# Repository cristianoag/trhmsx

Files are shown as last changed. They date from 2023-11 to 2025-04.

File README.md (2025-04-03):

# Introduction

>Unfortunately, there have been reports of unauthorized sales of this computer on platforms like Tindie, AliExpress and other obscure chinese marketplaces. We kindly ask you to support and reward the original creators of this project, who have generously shared their work with the retro community, rather than those engaging in unauthorized distribution. Thank you for respecting the creators' efforts and intentions.

MSX computers hold a significant place in computing history, and their legacy continues to be celebrated through innovative approaches like FPGA synthesis. Field-Programmable Gate Arrays (FPGAs) provide a unique platform for recreating the MSX architecture, offering a flexible and efficient way to re-create the hardware. 

This synthesis enables enthusiasts to experience the charm of MSX systems without relying on original, often scarce, hardware components. FPGA-based MSX simulations can faithfully replicate the distinctive features of these iconic computers, including the Z80 processor, graphics capabilities, and sound architecture. 

This modern approach not only preserves the nostalgia associated with MSX but also opens up possibilities for enhancements and customizations. FPGA synthesis ensures that the MSX spirit endures, catering to both seasoned aficionados and new generations eager to explore the roots of personal computing.

> **WARNING!** If you use this project to implement your own hardware, remember as per the license you must release the modified files under the same license. I've seen multiple projects based on files I publish on Github that were never released to the public, and I think that's a shame (and violation of the license!).

# TRHMSX - A Simple FPGA MSX2+ clone

This FPGA-based MSX2+ hardware represents a straightforward implementation, drawing inspiration from the original 1chipMSX circuit but featuring several enhancements and a new PCB design for improved functionality. Despite its advanced capabilities, the primary focus during development was on maintaining a low-cost solution.

The core of this system is the Cyclone I FPGA, accompanied by a few additional components. The PCB is a 4-layer board measuring 12x15 cm. The FPGA is a 240-pin package, which is challenging to solder manually. Instead, using an SMT oven or a hot air station is advised for optimal results. For those opting for a hot air station, employing a stencil to apply solder paste is highly recommended, significantly streamlining the assembly process.

| Kicad 3D Model | TRHMSX Computer |
|---|---|
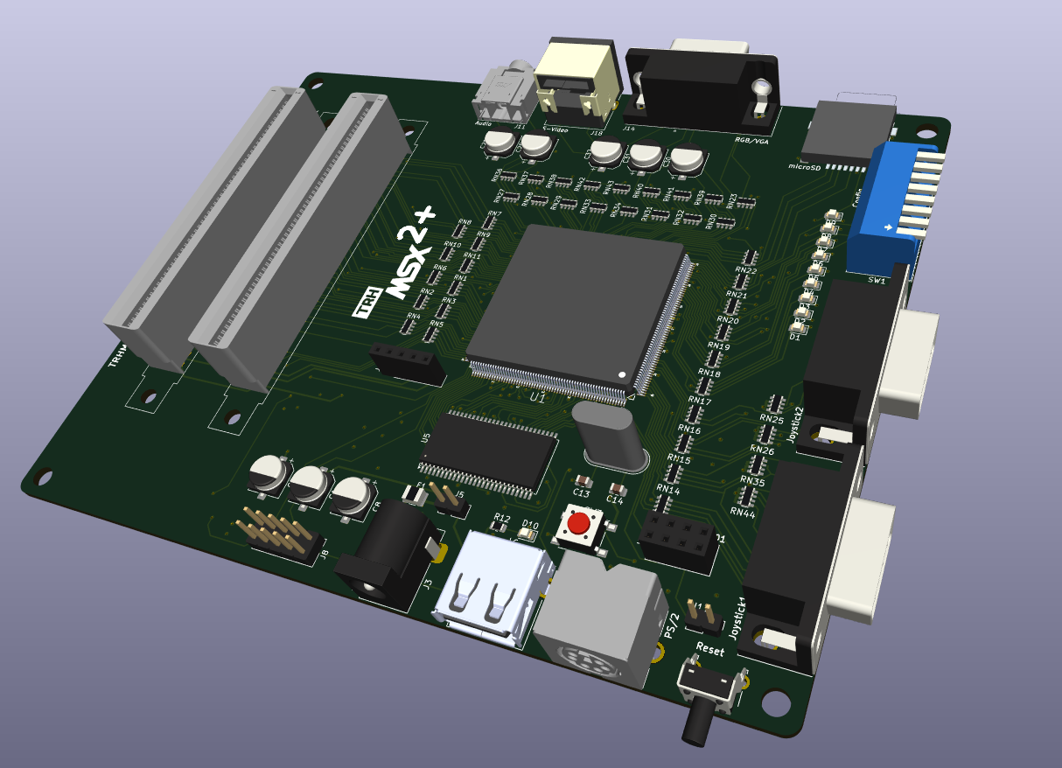
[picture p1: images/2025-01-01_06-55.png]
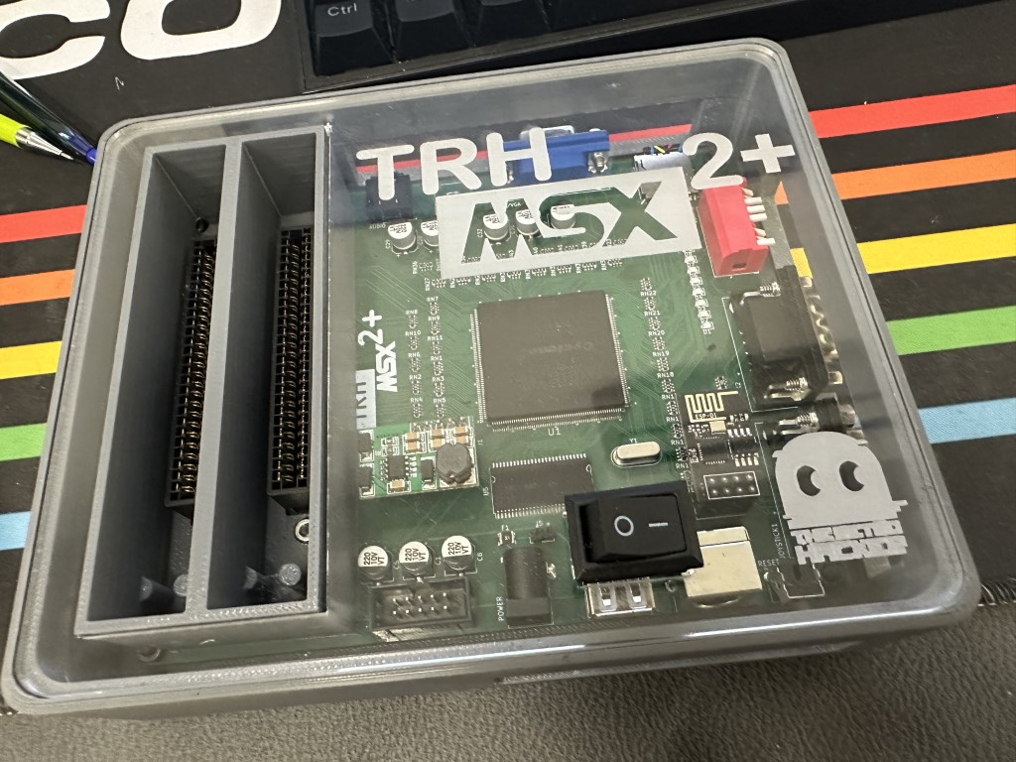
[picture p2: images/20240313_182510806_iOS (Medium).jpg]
|  |  |

Programming the FPGA requires the well-known OCM-PLD ESE MSX2+ core maintained by @gnogni (aka KDL), available for download [here](https://gnogni.altervista.org/) with the main development repository located at https://github.com/gnogni/ocm-pld-dev. This core ensures the proper functioning of the MSX2+ hardware, providing users with a reliable and authentic MSX experience on this FPGA-based system.

## Features

* **MSX2+ Compatibility**: Reproducing the MSX2+ architecture, ensuring compatibility with a wide range of software and games.
* **Expanded Memory Options**: Choose between 2MB or 4MB of mapped RAM, providing users with flexibility for diverse computing needs and applications.
* **9958 Video Display Processor (VDP)**: Incorporating the 9958 VDP for sharp graphics and improved visual performance, delivering an authentic MSX experience.
* **S-Video or VGA/RGB Video Output**: Supporting S-Video output for enhanced video quality or VGA/RGB output for compatibility with modern displays.
* **FM and SCC Sound Capabilities**: Featuring FM synthesis and SCC sound to reproduce the iconic audio characteristics of MSX systems, enhancing the overall gaming and multimedia experience.
* **Programmable Sound Generator (PSG)**: Including the original PSG for standard MSX audio output.
* **Keyboard Compatibility**: Supporting modern USB or PS/2 keyboards, providing users with a choice for their preferred input device.
* **MicroSD Card Support**: Integrating a microSD card slot for convenient storage and easy access to files, games, and software.
* **MSX Cartridge Slots**: Equipped with two MSX cartridge slots, allowing users to explore a vast library of MSX cartridges for an extended range of applications and games.
* **Dual Joystick Ports**: Featuring two joystick ports for multiplayer gaming and compatibility with classic MSX peripherals.
* **Wireless Network Support**: Incorporating wireless network support through the ESP8266, enabling online connectivity and expanding the possibilities for networked applications.
* **12V Cartridge Lines**: Providing dedicated 12V lines for cartridges, ensuring compatibility with a variety of peripherals and accessories.
* **Customizable Case Design**: Offering a 3D-printed base and transparent acrylic top cover, allowing users to customize the appearance of their TRHMSX system.

## Open Source

This project stands as a testament to the spirit of open source collaboration. Over the years, the original 1chipMSX circuit has inspired numerous clones, some even commercially implemented, each potentially harboring unique modifications. Regrettably, many of these adaptations were never shared with the broader community. In response, this project emerges as a fresh implementation of the original circuit, introducing enhancements and a redesigned PCB.

What sets this initiative apart is its commitment to transparency. From the project's inception, the goal was clear: to share all design files openly. This includes not only the schematics and PCB layout but also the Bill of Materials (BOM) and any other essential documentation for recreating the project.

In contrast to its predecessors, this project was conceived with a dedication to community collaboration. If you choose to utilize these resources to construct your own MSX2+ clone or find ways to enhance it, I encourage you to contribute back to the community. 

Share your experiences, document any improvements you make, and actively participate in the collective evolution of this open source initiative.

Let this project serve as a reminder of the **reciprocal nature of open source**. By using and benefiting from open source projects, it becomes a responsibility to give back, ensuring the continued growth and enrichment of the shared knowledge pool within the community.

## Bill of materials

The following table provides a comprehensive list of components required to build the latest version of the TRHMSX project. The BOM details the components, quantities, and references for each part.

I also provide links to the components on AliExpress or other sources, making it easier for you to purchase the necessary parts. 

 > **Note:** I don't have any affiliation with the sellers or guarantee the quality of the products. Please make sure to check the specifications and compatibility of the components before purchasing them.

| **Reference** | **Value** | **Description** | **Qty** | **Link** |
|---|---|---|---|---|
| **PCB** | | | | |
| TRHMSX PCB | N/A | Custom Printed Circuit Board for the TRHMSX 1.51 | 1 | [Gerber Files](hardware/trhmsx/production/TRHMSX_-_The_simple_MSX2_clone_in_FPGA_1.51.zip) |
| **Integrated Circuits (ICs)** | | | | |
| U1 | EP1C12Q240C8N | FPGA Cyclone Family 12060 Cells 275.03MHz 130nm Technology 1.5V 240-Pin PQFP | 1 | [AliExpress](https://s.click.aliexpress.com/e/_DEfxPNr) |
| U2 | AMS1117-1.5V | LOW DROPOUT VOLTAGE REGULATOR (1.5V) | 1 | [AliExpress](https://s.click.aliexpress.com/e/_DEu6go1) |
| U3 | AMS1117-3.3V | LOW DROPOUT VOLTAGE REGULATOR (3.3V) | 1 | [AliExpress](https://s.click.aliexpress.com/e/_DEu6go1) |
| U4 | NC7WZU04P6X | Dual Unbuffered Inverter | 1 | [AliExpress](https://s.click.aliexpress.com/e/_Dk6F9y9) |
| U5 | MT48LC16M16A2TG | 256Mb (4 Megabit x 16 x 4 banks) SYNCHRONOUS DRAM | 1 | [AliExpress](https://s.click.aliexpress.com/e/_DmOI4S5) |
| U6 | M51953BFP | Voltage Detector and System Reset IC | 1 | [AliExpress](https://s.click.aliexpress.com/e/_DnqwGxB) |
| U7 | CH559T | USB Host Micro-controller | 1 | [AliExpress](https://s.click.aliexpress.com/e/_oBU50ZV) |
| U8 | EPCS4 | 4 Mbit Serial Flash Memory (Altera Configuration) | 1 | [AliExpress](https://s.click.aliexpress.com/e/_DD2sMq9) |
| **Resistors** | | | | |
| RN27, RN28, RN29, RN30, RN31, RN32, RN33, RN34 | 200R | 0603X4 200R Resistor Array | 8 | [AliExpress](https://s.click.aliexpress.com/e/_DFFkTit) |
| RN1, RN2, RN3, RN4, RN5, RN6, RN7, RN8, RN9, RN10, RN11, RN13, RN14, RN15, RN16, RN19, RN20, RN21, RN22, RN23, RN36, RN37, RN38, RN39, RN40, RN41, RN42, RN43 | 100R | 0603X4 100R Resistor Array | 28 | [AliExpress](https://s.click.aliexpress.com/e/_DFFkTit) |
| RN12, RN25, RN26, RN35, RN44 | 10KR | 0603X4 10K R Resistor Array | 5 | [AliExpress](https://s.click.aliexpress.com/e/_DFFkTit) |
| RN17, RN18, RN24 | 1KR | 0603X4 1K R Resistor Array | 3 | [AliExpress](https://s.click.aliexpress.com/e/_DFFkTit) |
| R5, R12 | 1KR | 0805 1KR Resistor | 2 | [AliExpress](https://s.click.aliexpress.com/e/_DDTBoqV) |
| R13, R14 | 2.2KR | 0805 2.2KR Resistor | 2 | [AliExpress](https://s.click.aliexpress.com/e/_DDTBoqV) |
| R1, R2 | 10KR | 0805 10KR Resistor | 2 | [AliExpress](https://s.click.aliexpress.com/e/_DDTBoqV) |
| R3, R7 | 10R | 0805 10R Resistor | 2 | [AliExpress](https://s.click.aliexpress.com/e/_DDTBoqV) |
| R8, R9 | 100R | 0805 100R Resistor | 2 | [AliExpress](https://s.click.aliexpress.com/e/_DDTBoqV) |
| R10 | 22R | 0805 22R Resistor | 1 | [AliExpress](https://s.click.aliexpress.com/e/_DDTBoqV) |
| R11 | 1MR | 0805 1MR Resistor | 1 | [AliExpress](https://s.click.aliexpress.com/e/_DDTBoqV) |
| **Capacitors** | | | | |
| C2, C3, C4, C6, C7, C9, C10, C11, C12, C15, C16, C17, C18, C19, C20, C21, C22, C23, C24 | 0.1uF | 0805 100nF Ceramic Capacitor (104) | 19 | [AliExpress](https://s.click.aliexpress.com/e/_Dkt1yD7) |
| C13, C14 | 27pF | 0805 27pF Ceramic Capacitor (270) | 2 | [AliExpress](https://s.click.aliexpress.com/e/_Dkt1yD7) |
| C26, C27 | 4.7uF | 0805 4.7uF Ceramic Capacitor (475) | 2 | [AliExpress](https://s.click.aliexpress.com/e/_Dkt1yD7) |
| C33, C34 | 3.3uF | 0805 3.3uF Ceramic Capacitor (335) | 2 | [AliExpress](https://s.click.aliexpress.com/e/_Dkt1yD7) |
| C25 | 2.2uF | 0805 2.2uF Ceramic Capacitor (225) | 1 | [AliExpress](https://s.click.aliexpress.com/e/_Dkt1yD7) |
| C35 | 10uF | 0805 10uF Ceramic Capacitor (106) | 1 | [AliExpress](https://s.click.aliexpress.com/e/_Dkt1yD7) |
| C1, C5, C8, C28, C29, C30, C31, C32 | 220uF | Electrolytic Capacitor SMD 220uF 10V | 8 | [AliExpress](https://s.click.aliexpress.com/e/_DFJZp0V) |
| **LEDs and Switches** | | | | |
| D1, D2, D3, D4, D5, D6, D7, D8, D9, D10 | Any Color | LED 0805 SMD | 10 | [AliExpress](https://s.click.aliexpress.com/e/_DEuWUBP) |
| SW1 | DIP-SW-8P-RED-90G | Slide Type DIP Sided 90° Switch Module 8Pin Position Way 2.54mm Pitch Red Toggle Switch Blue Snap Switch Dial Switch | 1 | [AliExpress](https://s.click.aliexpress.com/e/_DdFF8Qd) |
| SW2 | BUTDIP90G6x6x12 | Momentary Tactile Tact Push Button Switch Right Angle Horizontal holder With Stent 6*6*12/mm | 1 | [AliExpress](https://s.click.aliexpress.com/e/_DdTON3T) |
| SW3 | BUTSMD180G6x6x4 | 6x6x4.3mm SMD Tactile Push Button Switch 4 Pin | 1 | [AliExpress](https://s.click.aliexpress.com/e/_ophZTzp) |
| **Connectors** | | | | |
| J3 | DC-005 | Female DC Power Jack supply socket 5.5X2.5mm DC-005 5.5-2.5MM Barrel | 1 | [AliExpress](https://s.click.aliexpress.com/e/_DdYmFPj) |
| J11 | PJ-307 | 3.5mm Stereo Jack Socket Audio Jack Connector PCB 3F07 PJ-307 | 1 | [AliExpress](https://s.click.aliexpress.com/e/_DCBm6IH) |
| J4 | MICROSDCARDHOLDER-F | MICROSD Card Holder Card Slot Card Holder Mobile Phone Memory Card Holder With Self-Elastic Long And Short Body | 1 | [AliExpress](https://s.click.aliexpress.com/e/_DeHRUZx) |
| J7 | PS26P-B | Keyboard socket PS2 6P black socket 6-pin Connector | 1 | [AliExpress](https://s.click.aliexpress.com/e/_Dci00lF) |
| J14 | DH15-F-SHORT-B | DH15 DR15 VGA Adapter Socket 3Rows Blue Parallel Port 15 Pin D Sub 15 Way PCB 90 Degree Female Connector | 1 | [AliExpress](https://s.click.aliexpress.com/e/_DEoqLMl) |
| J13, J16 | EDGE-50P | Edge Card Connector PCB Gold Finger 50 Pin | 2 | [AliExpress](https://s.click.aliexpress.com/e/_DkkR9k9) |
| J1 | PH-254-S-F-40 | Round Hole Pin Header 2.54MM Pitch Row Female, Single Row 1x40P | 1 | [AliExpress](https://s.click.aliexpress.com/e/_oFPYktN) |

## Building

To build the project you will need the following tools and resources:

* [Quartus Prime Lite Edition](https://fpgasoftware.intel.com/?edition=lite)
* [Quartus Prime Programmer](https://fpgasoftware.intel.com/18.1/?edition=lite&platform=windows&download_manager=dlm3)
* [USB Blaster drivers](https://fpgasoftware.intel.com/18.1/?edition=lite&platform=windows&download_manager=dlm3)
* [OCM-PLD Pack](https://gnogni.altervista.org/ocm/20221127%20OCM-PLD%20Pack%20v3.9.1%20by%20KdL.7z)

To guide the building process I recommend use the interactive BOM available here [here](https://htmlpreview.github.io/?https://github.com/cristianoag/trhmsx/blob/main/hardware/trhmsx/bom/ibom.html). As you get all the required parts and PCB, use the interactive BOM to check the components and their placement.

## Programming

The programming of the TRHMSX is divided into four main parts: the FPGA, the wireless network module, the USB host micro-controller, and the microSD card.

### FPGA
The firmware for the TRHMSX is based on the first generation esemsx VHDL/Verilog code. You can download the latest packages from KDL page [here](https://gnogni.altervista.org/), or get the latest development versions directly from his GitHub [here](https://github.com/gnogni/ocm-pld-dev).

If you are downloading from the page, you will need the OCM PLD Pack file. Download it and unzip its content in a local file on your PC. If you decide to use GitHub, clone the repository to your PC.

After the unzip, go to the latest version folder and navigate to esemsx3 folder. Check the README file, you will see that you need a pretty old Quartus II version (v11.0 SP1). That is because you are using an obsolete Altera FPGA chip that cannot be programmed by recent versions of the software.

Scrolling down on KDL page you will see a link to download the right version of Quartus. Download and install it.

> **Note:** I had issues with driver certificates for the USB blaster after installing this old version of Quartus. My USB blaster stopped working as the certificates for the driver in v11 are already expired. I reinstalled the latest version of Quartus on the same PC and everything worked fine after that.

Follow the instructions on the README file to compile the appropriate files and program your FPGA. Make sure to follow the instruction to convert the programming file and incorporate the emsx_top_304k.cof file, that way you will have an MSX computer with the EPBIOS. Those steps ensure that you will have the basic BIOS together with the programming file stored on the EPCS4, that will be useful in case you have any issues with the microSD card slot.

Connect your USB Blaster cable and use the Quartus programmer tool to upload the programming file to the EPCS4 flash.

When you turn on your TRHMSX after assembling the PCB, all LEDs should lit. During programming they will flash, turn off and after boot, the TRHMSX will flash the last LED indicating it is loading the synthesis to the FPGA chip, then it will lit only the LEDs that are correspondent to the configuration on the DIP switch bank.

Turn on 2 and 3 to have a 31Khz video and the last one (8) so you enable the SD card. If you need to understand what each dip switch does, check the doc file that is available [here](/docs/TRHMSX_1.5_Quick_Guide_EN.docx).

### USB Host Micro-controller

The latest version of the TRHMSX uses a CH559T micro-controller to handle the USB keyboard interface. That offers the possibility to use almost any USB keyboard with the computer, and not only the ones compatible with the PS/2 protocol.

The circuit from the [HIDMAN micro project](https://github.com/serisman/HIDman-mini/tree/main/KiCad%20PCBs/HIDman-micro) by [@serisman](https://github.com/serisman), based on the [original HIDMAN project](https://github.com/rasteri/HIDman/tree/main) by [Andy (@rasteri)](https://github.com/rasteri) was implemented on the computer. The solution uses the CH559T microcontroller from WCH (Nanjing QinHeng Electronics), a versatile 8051-based chip designed for USB applications.

The HIDMAN micro hardware and firmware offer a reliable way to adapt USB keyboards for PS/2 devices. Open-source hardware truly shines here, allowing to build on the amazing work of the community. Huge thanks to @rasteri and @serisman for their contributions!

To enable USB keyboard support, you’ll need to program the CH559 microcontroller. Here’s how:

1. **Prepare Your Tools**:
    * Download the WCH ISP Tool from [WCH’s website](https://www.wch-ic.com/downloads/WCHISPTool_Setup_exe.html) or from the TRHMSX GitHub repository if needed. I have a copy of the tool available [here](/software/WCHISPTool_Setup.exe).
    * If you are using macOS or Linux, install the [ch55xtool](https://github.com/MarsTechHAN/ch552tool).

2. **Connect Your Hardware**:
    * Power off the TRHMSX.
    * Use a USB A-to-A cable to connect the TRHMSX to your computer.

3. **Program the MCU**:
    * Launch the WCH ISP Tool and select the E8051 USB MCUs family.
    * Ensure the CH559 model is detected. If it isn’t, check the chip installation or bootloader status.
    * Download the pre-configured firmware for TRHMSX from the GitHub repository [here](/hardware/hidman-micro/firmware/dist/hidman.hex).
    * Follow the tool’s prompts to upload the firmware. Please refer to the following images for the tool configuration.

| WCH ISP Configuration| Firmware Download |
|---|---|
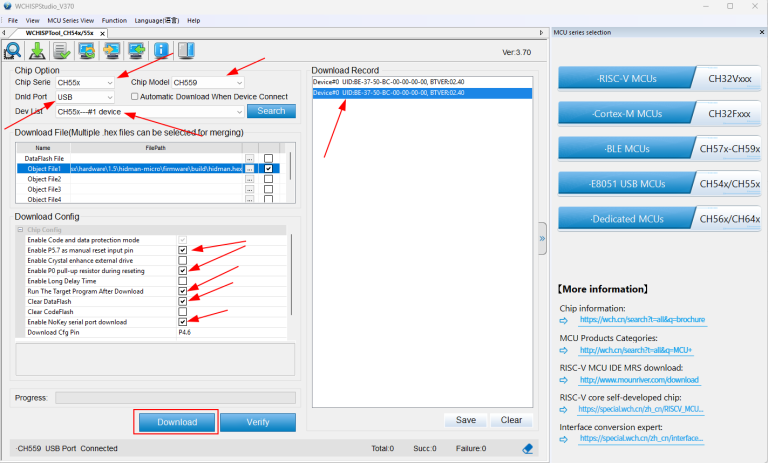
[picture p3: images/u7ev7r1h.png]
WCH ISP Tool
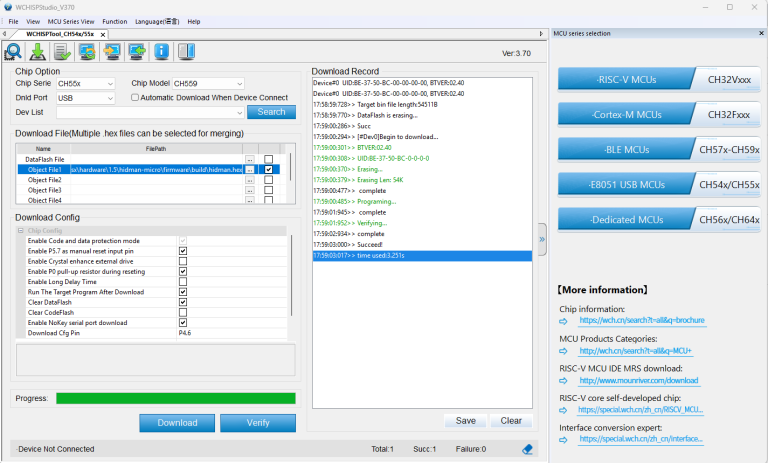
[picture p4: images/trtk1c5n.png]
WCH ISP Tool Configuration
|  |  |

### Wireless Network Module

Wireless network access in the TRHMSX is performed by the use of a 8266 ESP-01 module by Espressif and via the ESP8266 Wi-Fi Support Pack v1.0 shared by KDL as the result of the work of Oduvaldo Pavan Jr. The software created by Oduvaldo is licensed under the GNU Lesser General Public License v2.1 as open source and it is available both from the KDL original web page as well as directly from Oduvaldo's GitHub repository at https://github.com/ducasp/ESP8266-UNAPI-Firmware/ 

Note: Oduvaldo has been working in optimized versions of the ESP8266 module to be used with other FPGA based computers and those may not be compatible with the TRHMSX. Please use the one shared by KDL as it was built to be used with the basic Verilog/VHDL ESEMSX.

#### Programming the ESP8266 module

To program the ESP-01 module you will need a CH340 USB to ESP8266 ESP01 Serial Programmer like the one shown in the below picture. You can purchase one of those directly from AliExpress [here](https://www.aliexpress.com/item/32971145094.html?spm=a2g0o.order_list.order_list_main.30.768e1802iucYdq) (the link is also available on the Bill of Materials table in this document).

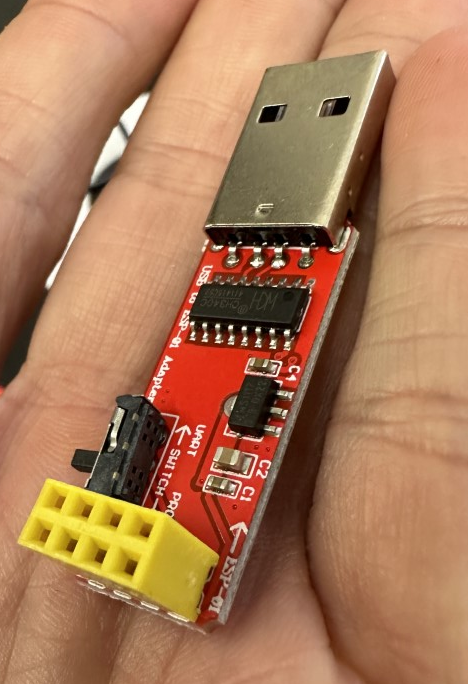
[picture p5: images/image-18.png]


Follow the instructions detailed below to program your ESP8266 module:

1. Download the ESP8266 Wi-Fi Support Pack v1.0 from the KDL page [here](https://gnogni.altervista.org/ocm/20210823%20ESP8266%20Wi-Fi%20Support%20Pack%20v1.0%20by%20KdL.7z). 
2. Make sure the switch on the programmer is configured to PROG.
3. Connect the ESP-01 module to the programmer and insert it to your PC USB port. Open device manager and check the COM port assigned to the programmer. Make sure you have the appropriate CG340 driver installed, if required download and install the driver from wch.cn/downloads/CH341SER_EXE.html

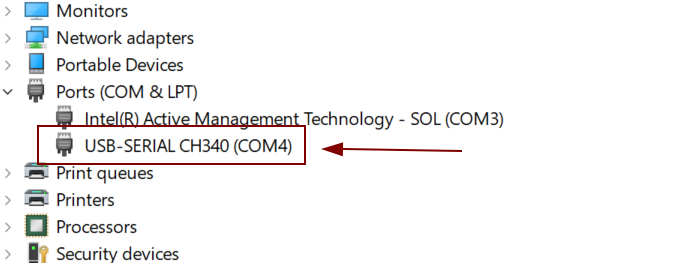
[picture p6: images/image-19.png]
&nbsp;&nbsp;&nbsp;&nbsp;&nbsp;&nbsp;&nbsp;&nbsp;&nbsp;&nbsp;&nbsp;

4. Download Espressif Flash Download Tools from Tools | Espressif Systems
5. Unzip and execute the Flash Download tool from the downloaded zip package. 
6. If asked, select the ESP8266 ChipType and Develop as the WorkMode. Click OK to run the flash download tool.

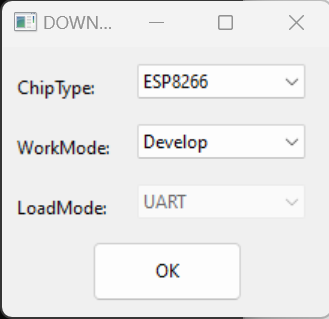
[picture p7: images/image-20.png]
&nbsp;&nbsp;&nbsp;&nbsp;&nbsp;&nbsp;&nbsp;&nbsp;&nbsp;&nbsp;&nbsp;

7. Click the elipsis on the first two lines and make sure to select certs.bin and fw.bin from the package downloaded from the KDL page. Those files are located on the bin folder after unziping the package.  Use 0x0 as the start address for fw.bin and 0xbb000 for certs.bin. Also make sure to select the same COM port as the port identified previously as being used by the CH340 programmer. Reference to the picture below when running the flash download tool to program your ESP8266 module.

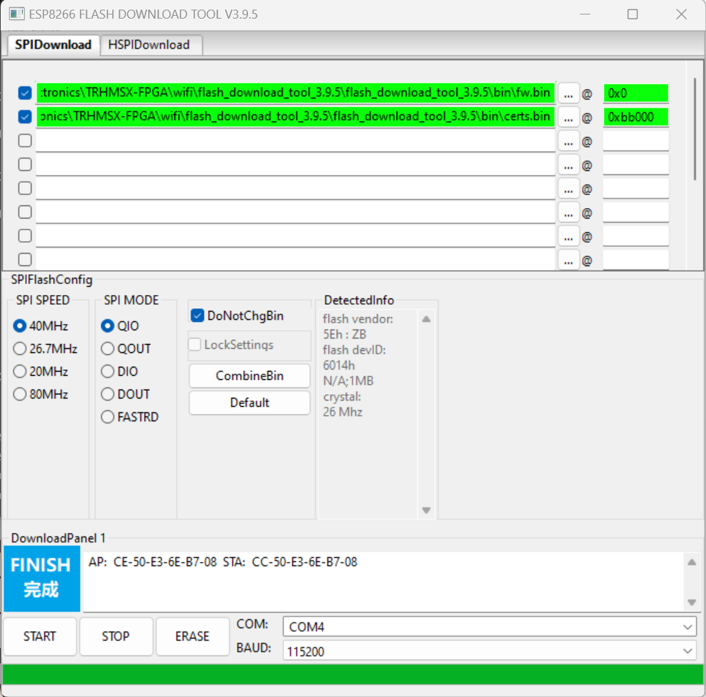
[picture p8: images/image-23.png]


8. The ESP8266 is now ready to be inserted into the TRH MSX pin header dedicated to host the module.

#### Using the TRHMSX with Wireless 

To connect the TRHMSX to your wireless network you need first program the 8266 module according to the instructions previously documented. Then go ahead and plug the module to the appropriate pin headers on the board. Make sure you are connecting it with the right orientation. The location of the header was intentionally chosen to avoid wrong connections as the board cannot be over the SMD electrolytic capacitors located nearby.

Now turn on the TRHMSX and push the F1 key. Keep it pushed until you see the message shown below.

| Entering Network Setup | Config Menu|
|---|---|
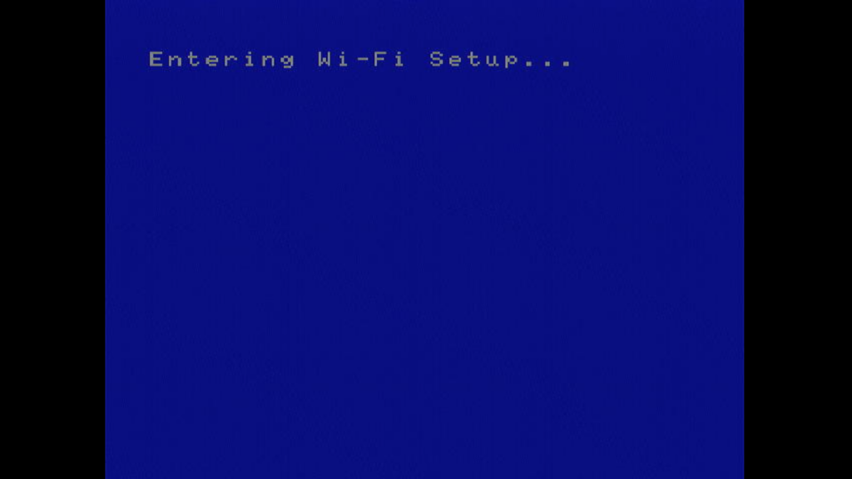
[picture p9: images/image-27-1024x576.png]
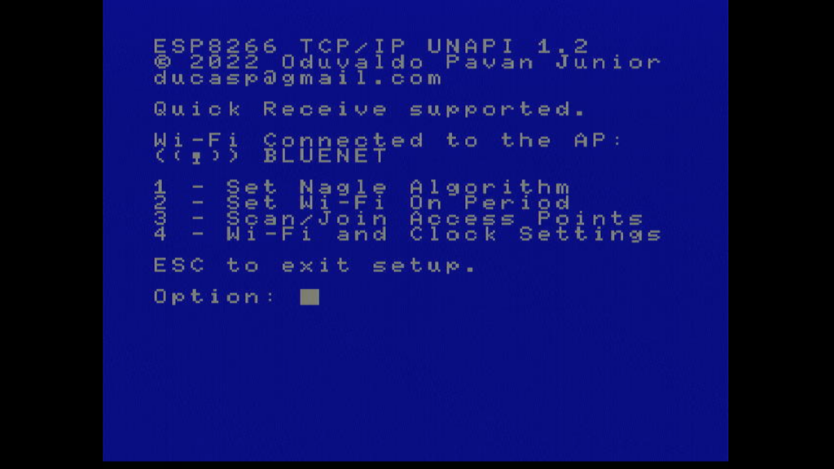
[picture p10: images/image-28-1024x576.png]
||

Note that the second screen already shows it is connected to my local wireless network. You may get a message saying the module is still not connected to any access point. 

Using option 3 you can select a network to connect and provide appropriate credentials. The other options change specific firmware configurations. Please consult the firmware documentation to obtain details on the options and specific configurations.

After connecting the module to your wireless network you can use any UNAPI compatible tool from the computer. Just be aware that the AT firmware variant implemented by Oduvaldo doesn't support ICMP, thus the PING command that we normally use to test the OBSONETs and other traditional network cards will not work from the TRHMSX with the ESP8266 module.

### microSD Card

The microSD card is created by running two tools. The first will build the appropriate files for the card and the second will format, and copy the files to the card.

To configure the files for your microSD card, follow the steps below:

1. Download the latest version of the KDL OCM-SDBIOS pack from the KDL page [here](https://gnogni.altervista.org/).
2. Unzip the downloaded file to a local folder on your PC.
3. Open a command prompt and navigate to the folder where you unzipped the files.
4. Run the make-sdb.cmd tool that is located inside the "make" folder. 
5. Press ENTER on the first screen
6. On the Firmware Menu screen, select option 2 (default) and press ENTER
7. On the Disk-ROM Menu screen, select option 1 (default) and press ENTER
8. On the Main-ROM Menu screen, select option 2 (default) and press ENTER
9. On the Kanji-ROM Menu screen, select the option you want for the splash screen and press ENTER
10. On the Option-ROM Menu screen, select the option 2 to enable the ESP8266 Wifi BIOS for the TRHMSX and press ENTER.
11. On the Extra-ROM Menu screem, select option 3 (default) and press ENTER

Wait until the tool finishes creating the files. After that, you can folow the steps below to build the card using the files you just configured.

1. Insert the microSD card into your PC.
2. Run the SD Card building tool by executing the file named new-sdcard.cmd inside the "make" folder.
3. Select the drive corresponding to your microSD card and press Enter. Optionally provide a name for the partition.
 4. Press any key to create the partition and format the card.

After creating the microSD card, insert it into the TRHMSX and turn on the computer. The TRHMSX will boot from the microSD card and you will see the MSX-DOS prompt.

Optionally, install SofaRun and copy a few ROMs to the card to test the computer.

### +12V/-12V Cartridge Lines

Certain MSX cartridges utilize both the +12V and -12V lines, such as specific variants of OPL4 cartridges and the RBSC Carnivore2. Those lines are crucial for powering the operational amplifiers responsible for audio output.

In the case of the TRHMSX, the +-12V lines are generated through a simple DC Step-up Boost Converter module  connected to the relevant pin headers on the motherboard. 

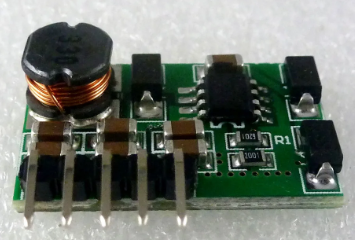
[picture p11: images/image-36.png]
DC Step-up Boost Converter module


The board is powered by the 5V line from the TRHMSX and generates the required +-12V lines. The board is then connected to the TRHMSX motherboard through the relevant pin headers, providing the necessary power for cartridges requiring both +12V and -12V lines.

It can be ordered from AliExpress [here](https://www.aliexpress.com/item/32789671683.html?spm=a2g0o.order_list.order_list_main.16.36c21802vzMe7h).

## Case

The computer case is a combination of a 3D printed bed and a transparent acrylic top cover. There is also the option to print a top cover using transparent or translucid filament or resin. I'm providing Lightburn and STL files for either option on the case folder.

|3D model for the case|First prototype in the case|
|---|---|
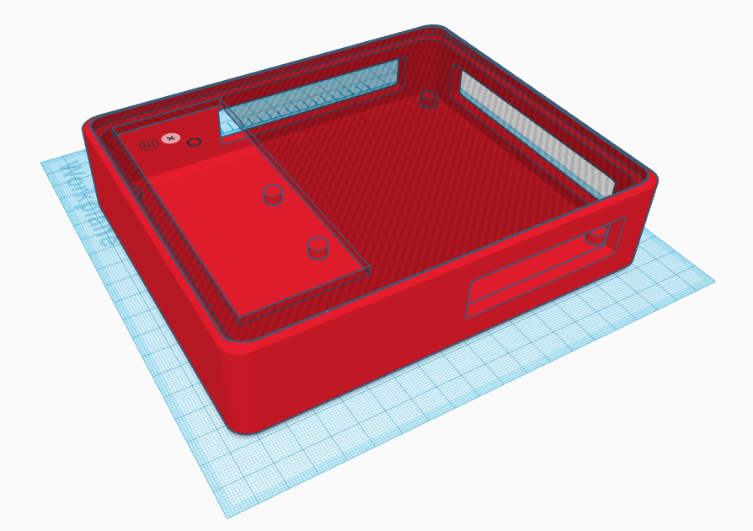
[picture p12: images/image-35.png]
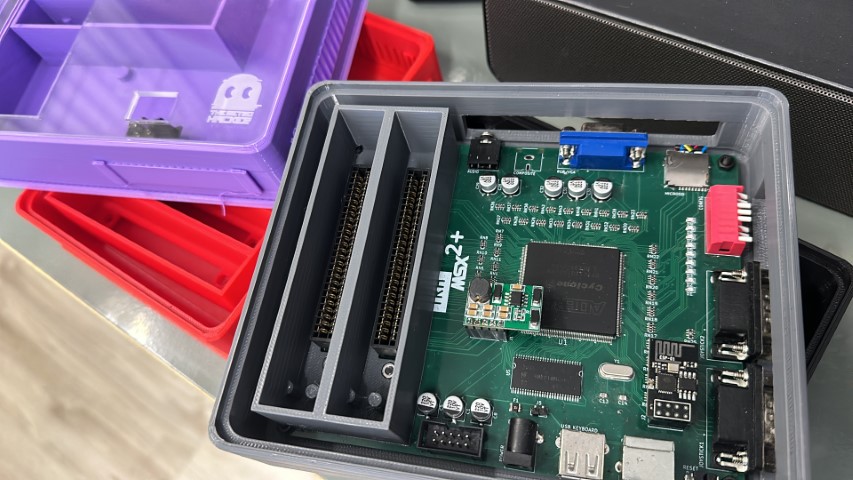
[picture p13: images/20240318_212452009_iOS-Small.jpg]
|||

The STL file to print the case is available [here](case/TRHMSX_case_base_v1.5.stl). You will also need the file to print the cartridge guide [here](case/TRHMSX_cart_guide_v1.4.stl).

Additionally I made available covers for all case and top cover holes so you can protect the computer from dust when not using it. Those files are available on the case folder as well.

The acrylic top is cut from a 3mm transparent acrylic sheet.
The SVG and Light Burn files to cut the acrylic top are available [here](case/). If you decide to print the top cover with the transparent filament or resin, please use the following STL file [TRHMSX_Translucent_Cover.stl](case/TRHMSX_Translucent_Cover.stl)

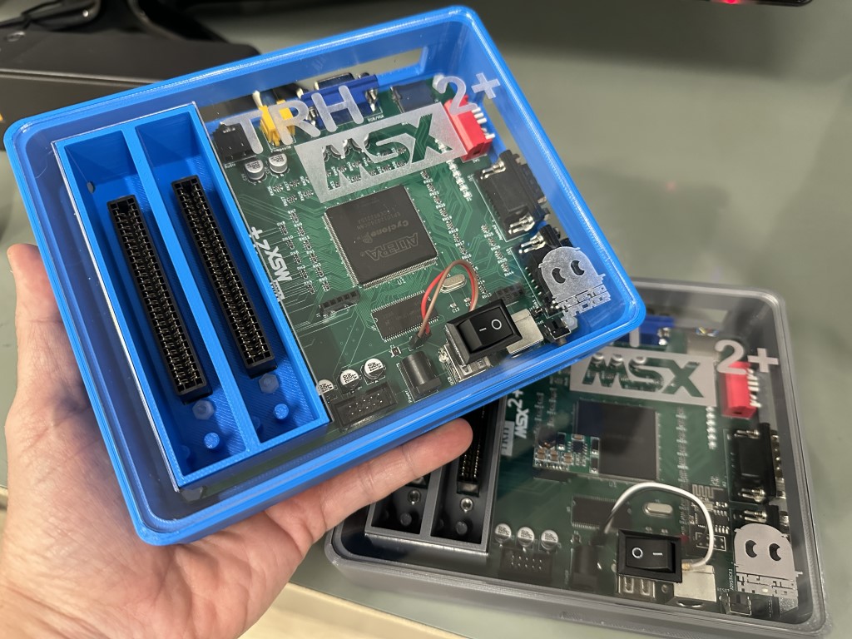
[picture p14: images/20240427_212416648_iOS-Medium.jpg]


## License

Open Hardware

This work is licensed under a [Creative Commons Attribution-NonCommercial-ShareAlike 4.0 International License](http://creativecommons.org/licenses/by-nc-sa/4.0/).

* If you remix, transform, or build upon the material, you must distribute your contributions under the same license as the original.
* You may not use the material for commercial purposes.
* You must give appropriate credit, provide a link to the license, and indicate if changes were made. You may do so in any reasonable manner, but not in any way that suggests the licensor endorses you or your use.

**ATTENTION**

This project was made for the retro community and not for commercial purposes. So only retro hardware forums and individual people can build this project.

THE SALE OF ANY PART OF THIS PROJECT WITHOUT EXPRESS AUTHORIZATION IS PROHIBITED!

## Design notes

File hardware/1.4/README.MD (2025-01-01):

# TRHMSX 1.4

This is the hardware repository for the TRHMSX 1.4. The TRHMSX is a simple FPGA MSX2 clone that uses an Altera Cyclone FPGA to emulate the MSX2 computer. 

The interactive BOM can be found [here](https://htmlpreview.github.io/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).  

Below you can find a list of the components used in the TRHMSX 1.4. The links provided are just suggestions. I don't have any affiliation with the sellers or guarantee the quality of the products. Please make sure to check the specifications and compatibility of the components before purchasing them.

## V1.4 Bill of materials

<table><tbody><tr><td><strong>Reference</strong></td><td><strong>Value</strong></td><td><strong>Description</strong></td><td><strong>Qty</strong></td><td><strong>Link</strong></td></tr><tr><td>TRHMSX PCB</td><td>N/A</td><td>Custom Printer Circuit Board for the TRHMSX 1.0</td><td>1</td><td><a href="https://www.pcbway.com/project/shareproject/TRHMSX_A_Simple_FPGA_MSX2_clone_c575151d.html" data-type="link" data-id="https://www.pcbway.com/project/shareproject/TRHMSX_A_Simple_FPGA_MSX2_clone_c575151d.html">PCBWay</a></td></tr><tr><td>U1</td><td>EP1C12Q240C8N</td><td>FPGA Cyclone Family 12060 Cells 275.03MHz 130nm Technology 1.5V 240-Pin PQFP</td><td>1</td><td><a href="https://s.click.aliexpress.com/e/_DEfxPNr" data-type="link" data-id="https://s.click.aliexpress.com/e/_DEfxPNr">AliExpress</a></td></tr><tr><td>RN27, RN28, RN29, RN30, RN31, RN32, RN33, RN34</td><td>200R</td><td>0603X4 200R Resistor Array</td><td>8</td><td><a href="https://s.click.aliexpress.com/e/_DFFkTit" data-type="link" data-id="https://s.click.aliexpress.com/e/_DFFkTit">AliExpress</a></td></tr><tr><td>RN1, RN2, RN3, RN4, RN5, RN6, RN7, RN8, RN9, RN10, RN11, RN13, RN14, RN15, RN16, RN19, RN20, RN21, RN22, RN23, RN36, RN37, RN38, RN39, RN40, RN41, RN42, RN43</td><td>100R</td><td>0603X4 100R Resistor Array</td><td>28</td><td><a href="https://s.click.aliexpress.com/e/_DFFkTit" data-type="link" data-id="https://s.click.aliexpress.com/e/_DFFkTit">AliExpress</a></td></tr><tr><td>RN12, RN25, RN26, RN35, RN44</td><td>10KR</td><td>0603X4 10K R Resistor Array</td><td>5</td><td><a href="https://s.click.aliexpress.com/e/_DFFkTit" data-type="link" data-id="https://s.click.aliexpress.com/e/_DFFkTit">AliExpress</a></td></tr><tr><td>RN17, RN18, RN24</td><td>1KR</td><td>0603X4 1K R Resistor Array</td><td>3</td><td><a href="https://s.click.aliexpress.com/e/_DFFkTit" data-type="link" data-id="https://s.click.aliexpress.com/e/_DFFkTit">AliExpress</a></td></tr><tr><td>C2, C3, C4, C6, C7, C9, C10, C11, C12, C15, C16, C17, C18, C19, C20, C21, C22, C23, C24</td><td>0.1uF</td><td>0805 100nF Ceramic Capacitor (104)</td><td>19</td><td><a href="https://s.click.aliexpress.com/e/_Dkt1yD7" data-type="link" data-id="https://s.click.aliexpress.com/e/_Dkt1yD7">AliExpress</a></td></tr><tr><td>C13, C14</td><td>27pF</td><td>0805 27pF Ceramic Capacitor (270)</td><td>2</td><td><a href="https://s.click.aliexpress.com/e/_Dkt1yD7" data-type="link" data-id="https://s.click.aliexpress.com/e/_Dkt1yD7">AliExpress</a></td></tr><tr><td>C26, C27</td><td>4.7uF</td><td>0805 4.7uF Ceramic Capacitor (475)</td><td>2</td><td><a href="https://s.click.aliexpress.com/e/_Dkt1yD7" data-type="link" data-id="https://s.click.aliexpress.com/e/_Dkt1yD7">AliExpress</a></td></tr><tr><td>C25</td><td>2.2uF</td><td>0805 2.2uF Ceramic Capacitor (225)</td><td>1</td><td><a href="https://s.click.aliexpress.com/e/_Dkt1yD7" data-type="link" data-id="https://s.click.aliexpress.com/e/_Dkt1yD7">AliExpress</a></td></tr><tr><td>D1, D2, D3, D4, D5, D6, D7, D8, D9</td><td>Any Color</td><td>LED 0805 SMD</td><td>9</td><td><a href="https://s.click.aliexpress.com/e/_DEuWUBP" data-type="link" data-id="https://s.click.aliexpress.com/e/_DEuWUBP">AliExpress</a></td></tr><tr><td>R4, R5, R6</td><td>1KR</td><td>0805 1KR Resistor</td><td>3</td><td><a href="https://s.click.aliexpress.com/e/_DDTBoqV" data-type="link" data-id="https://s.click.aliexpress.com/e/_DDTBoqV">AliExpress</a></td></tr><tr><td>R1, R2</td><td>10KR</td><td>0805 10KR Resistor</td><td>2</td><td><a href="https://s.click.aliexpress.com/e/_DDTBoqV" data-type="link" data-id="https://s.click.aliexpress.com/e/_DDTBoqV">AliExpress</a></td></tr><tr><td>R3, R7</td><td>10R</td><td>0805 10R Resistor</td><td>2</td><td><a href="https://s.click.aliexpress.com/e/_DDTBoqV" data-type="link" data-id="https://s.click.aliexpress.com/e/_DDTBoqV">AliExpress</a></td></tr><tr><td>R8, R9</td><td>100R</td><td>0805 100R Resistor</td><td>2</td><td><a href="https://s.click.aliexpress.com/e/_DDTBoqV" data-type="link" data-id="https://s.click.aliexpress.com/e/_DDTBoqV">AliExpress</a></td></tr><tr><td>R10</td><td>22R</td><td>0805 22R Resistor</td><td>1</td><td><a href="https://s.click.aliexpress.com/e/_DDTBoqV" data-type="link" data-id="https://s.click.aliexpress.com/e/_DDTBoqV">AliExpress</a></td></tr><tr><td>R11</td><td>1MR</td><td>0805 1MR Resistor</td><td>1</td><td><a href="https://s.click.aliexpress.com/e/_DDTBoqV" data-type="link" data-id="https://s.click.aliexpress.com/e/_DDTBoqV">AliExpress</a></td></tr><tr><td>U2</td><td>AMS1117-1.5V</td><td>LOW DROPOUT VOLTAGE REGULATOR (1.5V)</td><td>1</td><td><a href="https://s.click.aliexpress.com/e/_DEu6go1" data-type="link" data-id="https://s.click.aliexpress.com/e/_DEu6go1">AliExpress</a></td></tr><tr><td>U3</td><td>AMS1117-3.3V</td><td>LOW DROPOUT VOLTAGE REGULATOR (3.3V)</td><td>1</td><td><a href="https://s.click.aliexpress.com/e/_DEu6go1" data-type="link" data-id="https://s.click.aliexpress.com/e/_DEu6go1">AliExpress</a></td></tr><tr><td>U5</td><td>MT48LC16M16A2TG</td><td>256Mb (4 Megabit x 16 x 4 banks) SYNCHRONOUS DRAM</td><td>1</td><td><a href="https://s.click.aliexpress.com/e/_DmOI4S5" data-type="link" data-id="https://s.click.aliexpress.com/e/_DmOI4S5">AliExpress</a></td></tr><tr><td>U6</td><td>M51953BFP</td><td>Voltage Detector and System Reset IC</td><td>1</td><td><a href="https://s.click.aliexpress.com/e/_DnqwGxB" data-type="link" data-id="https://s.click.aliexpress.com/e/_DnqwGxB">AliExpress</a></td></tr><tr><td>F1</td><td>FUSEPPTC-1.5A6V</td><td>PPTC Fuse 6V 1.5A 1210</td><td>1</td><td><a href="https://s.click.aliexpress.com/e/_DCOB4CZ" data-type="link" data-id="https://s.click.aliexpress.com/e/_DCOB4CZ">AliExpress</a></td></tr><tr><td>IC1</td><td>EPCS4</td><td>4 Mbit Serial Flash Memory (Altera Configuration)</td><td>1</td><td><a href="https://s.click.aliexpress.com/e/_DD2sMq9" data-type="link" data-id="https://s.click.aliexpress.com/e/_DD2sMq9">AliExpress</a></td></tr><tr><td>U4</td><td>NC7WZU04P6X</td><td>Dual Unbuffered Inverter</td><td>1</td><td><a href="https://s.click.aliexpress.com/e/_Dk6F9y9" data-type="link" data-id="https://s.click.aliexpress.com/e/_Dk6F9y9">AliExpress</a></td></tr><tr><td>C1, C5, C8, C28, C29, C30, C31, C32</td><td>220uF</td><td>Electrolytic Capacitor SMD 220uF 10V</td><td>8</td><td><a href="https://s.click.aliexpress.com/e/_DFJZp0V" data-type="link" data-id="https://s.click.aliexpress.com/e/_DFJZp0V">AliExpress</a></td></tr><tr><td>J3</td><td>DC-005</td><td>Female DC Power Jack supply socket 5.5X2.5mm DC-005 5.5-2.5MM Barrel</td><td>1</td><td><a href="https://s.click.aliexpress.com/e/_DdYmFPj" data-type="link" data-id="https://s.click.aliexpress.com/e/_DdYmFPj">AliExpress</a></td></tr><tr><td>J11</td><td>PJ-307</td><td>3.5mm Stereo Jack Socket Audio Jack Connector PCB 3F07 PJ-307</td><td>1</td><td><a href="https://s.click.aliexpress.com/e/_DCBm6IH" data-type="link" data-id="https://s.click.aliexpress.com/e/_DCBm6IH">AliExpress</a></td></tr><tr><td>J4</td><td>MICROSDCARDHOLDER-F</td><td>MICROSD Card Holder Card Slot Card Holder Mobile Phone Memory Card Holder With Self-Elastic Long And Short Body</td><td>1</td><td><a href="https://s.click.aliexpress.com/e/_DeHRUZx" data-type="link" data-id="https://s.click.aliexpress.com/e/_DeHRUZx">AliExpress</a></td></tr><tr><td>J7</td><td>PS26P-B</td><td>Keyboard socket PS2 6P black socket 6-pin Connector</td><td>1</td><td><a href="https://s.click.aliexpress.com/e/_Dci00lF" data-type="link" data-id="https://s.click.aliexpress.com/e/_Dci00lF">AliExpress</a></td></tr><tr><td>J14</td><td>DH15-F-SHORT-B</td><td>DH15 DR15 VGA Adapter Socket 3Rows Blue Parallel Port 15 Pin D Sub 15 Way PCB 90 Degree Female Connector</td><td>1</td><td><a href="https://s.click.aliexpress.com/e/_DEoqLMl" data-type="link" data-id="https://s.click.aliexpress.com/e/_DEoqLMl">AliExpress</a></td></tr><tr><td>SW1</td><td>DIP-SW-8P-RED-90G</td><td>Slide Type DIP Sided 90o Switch Module 8Pin Position Way 2.54mm Pitch Red Toggle Switch Blue Snap Switch Dial Switch</td><td>1</td><td><a href="https://s.click.aliexpress.com/e/_DdFF8Qd" data-type="link" data-id="https://s.click.aliexpress.com/e/_DdFF8Qd">AliExpress</a></td></tr><tr><td>J12</td><td>RCA-YELLOW-3P</td><td>AV Socket AV-8.4-5 Three Pin Single Hole Socket Yellow Side Bent Foot RCA Lotus Audio Socket Connector</td><td>1</td><td><a href="https://s.click.aliexpress.com/e/_DFjsw5T" data-type="link" data-id="https://s.click.aliexpress.com/e/_DFjsw5T">AliExpress</a></td></tr><tr><td>J6</td><td>USB-A</td><td>USB Type A Standard Port Female Solder Jacks Connector PCB Socket USB-A type</td><td>1</td><td><a href="https://s.click.aliexpress.com/e/_DlKAwlj" data-type="link" data-id="https://s.click.aliexpress.com/e/_DlKAwlj">AliExpress</a></td></tr><tr><td>J8</td><td>BOXED-2x5P-2.54-180</td><td>Straight 10 PIN 2.54MM pitch MALE SOCKET idc box headers PCB CONNECTOR DOUBLE ROW</td><td>1</td><td><a href="https://s.click.aliexpress.com/e/_DdnF7VJ" data-type="link" data-id="https://s.click.aliexpress.com/e/_DdnF7VJ">AliExpress</a></td></tr><tr><td>J15, J10</td><td>DB9-M-LONG-BLACK</td><td>DB9 Male PCB Mount D-Sub 9 pin PCB Connector RS232 Connector 90-degree Bent Needle DR9</td><td>2</td><td><a href="https://s.click.aliexpress.com/e/_DEPBDln" data-type="link" data-id="https://s.click.aliexpress.com/e/_DEPBDln">AliExpress</a></td></tr><tr><td>SW2</td><td>BUTDIP90G6x6x12</td><td>Momentary Tactile Tact Push Button Switch Right Angle Horizontal holder With Stent 6<em>6</em>12/mm</td><td>1</td><td><a href="https://s.click.aliexpress.com/e/_DdTON3T" data-type="link" data-id="https://s.click.aliexpress.com/e/_DdTON3T">AliExpress</a></td></tr><tr><td>Y1</td><td>21.47727 Mhz</td><td>21.47727M 21.47727MHZ 20PF QUARTZ CRYSTAL RESONATOR HC-49S</td><td>1</td><td><a href="https://s.click.aliexpress.com/e/_DmkZXqZ" data-type="link" data-id="https://s.click.aliexpress.com/e/_DmkZXqZ">AliExpress</a></td></tr><tr><td>CART1, CART2</td><td>EDGE-50P</td><td>Edge Card Connector PCB Gold Finger 50 Pin</td><td>2</td><td><a href="https://s.click.aliexpress.com/e/_DkkR9k9" data-type="link" data-id="https://s.click.aliexpress.com/e/_DkkR9k9">AliExpress</a></td></tr><tr><td>N/A</td><td>PH-254-S-F-40-ROUNDED</td><td>Round Hole Pin Header 2.54MM Pitch Row Female/Male, Single Row 1x40P</td><td>1</td><td><a href="https://s.click.aliexpress.com/e/_DlfZNmh" data-type="link" data-id="https://s.click.aliexpress.com/e/_DlfZNmh">AliExpress</a></td></tr><tr><td>N/A</td><td>PH-254-S-M-40-ROUNDED</td><td>2.54mm Pitch Gold Plated Male 40P 1*40 Round Pin Header Strip Hole Single Row Straight Socket Connector</td><td>1</td><td><a href="https://s.click.aliexpress.com/e/_DlfZNmh" data-type="link" data-id="https://s.click.aliexpress.com/e/_DlfZNmh">AliExpress</a></td></tr><tr><td>J2</td><td>ESP-01</td><td>ESP8266 WIFI wireless module wireless transceiver 2.4G ESP-01</td><td>1</td><td><a href="https://s.click.aliexpress.com/e/_Ddjghnr" data-type="link" data-id="https://s.click.aliexpress.com/e/_Ddjghnr">AliExpress</a></td></tr><tr><td>N/A</td><td>ESP-01 Programmer</td><td>CH340 USB to ESP8266 Serial ESP-01 ESP-01S Adapter Wireless Wifi Developent Board ESP01 ESP01S Programmer Adapter GPIO Module</td><td>1</td><td><a href="https://s.click.aliexpress.com/e/_Ddjghnr" data-type="link" data-id="https://s.click.aliexpress.com/e/_Ddjghnr">AliExpress</a></td></tr><tr><td>N/A</td><td>DCDCSTEP12V</td><td>+-12V Positive &amp; Negative Dual Output power supply DC DC Step-up Boost Converter module</td><td>1</td><td><a href="https://www.aliexpress.com/item/32789671683.html?spm=a2g0o.order_detail.order_detail_item.5.5cc6f19ccbtJLv" data-type="link" data-id="https://www.aliexpress.com/item/32789671683.html?spm=a2g0o.order_detail.order_detail_item.5.5cc6f19ccbtJLv">AliExpress</a></td></tr></tbody></table>

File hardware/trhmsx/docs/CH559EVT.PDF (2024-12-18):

## USB 单片机 CH559 的评估板说明

## 1、硬件部分

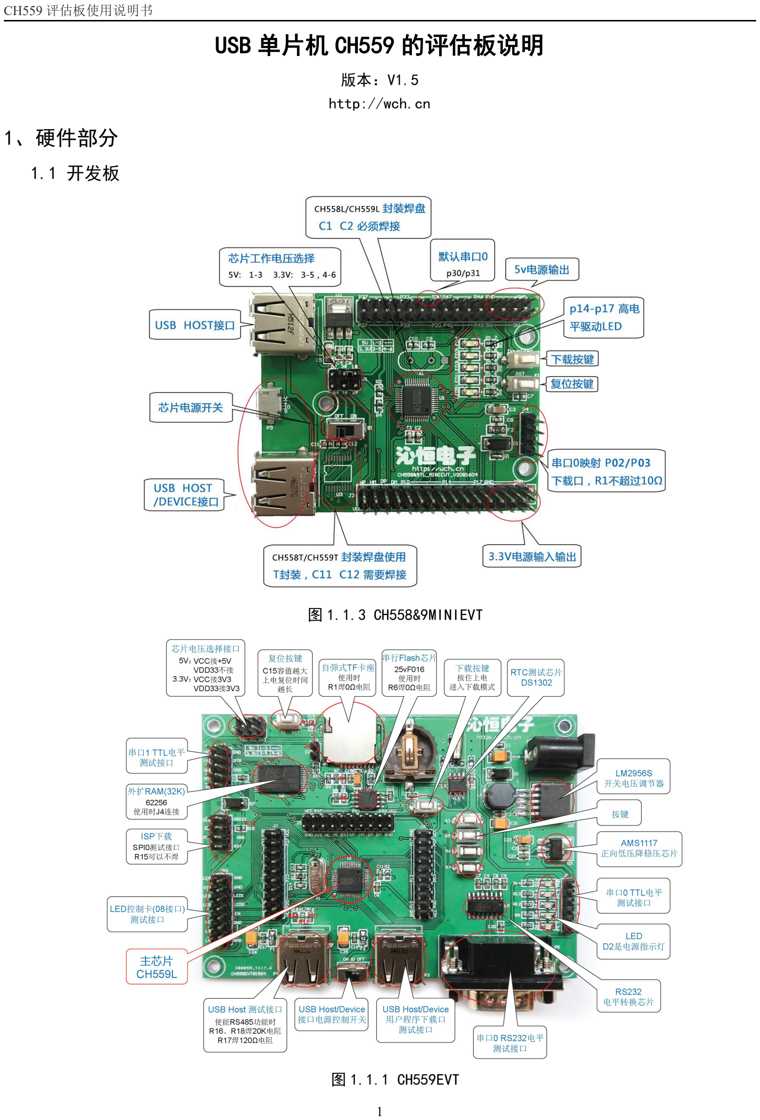
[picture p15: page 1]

CH559 评估板使用说明书

版本：V1.5
http://wch.cn

1.1 开发板

图 1.1.3 CH558&9MINIEVT

图 1.1.1 CH559EVT

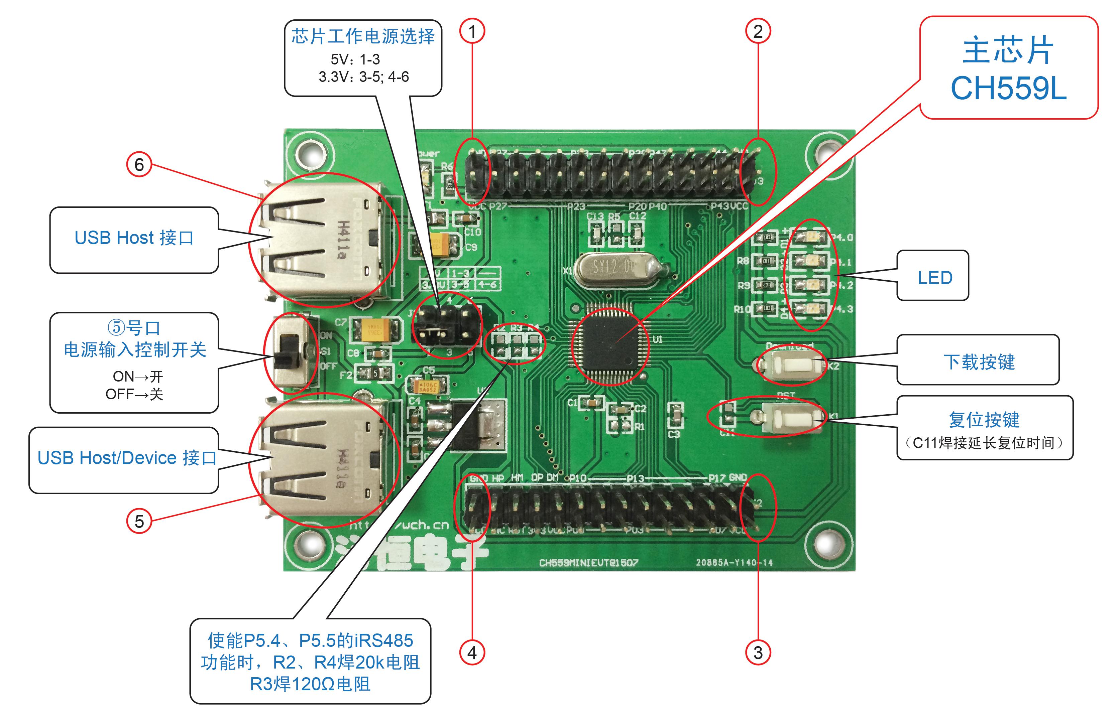
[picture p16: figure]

图 1.1.2 CH559MINIEVT

1.2 开发板主芯片及功能说明
(1)、芯片工作电源选择：芯片电压选择，VCC 和+5V 短接，VDD33 悬空，CH559 的工作电压选为 5V；VCC 和 3V3 短接，VDD33 和 3V3 短接，CH559 工作电压选为 3.3V；
(2)、评估板电源输入：
通过 P1 电源适配器插口输入 8-15V 的电压，如图 1.1.1 的 P1 口；
通过 USB 直接输入 5V 电压，如图 1.1.1 和图 1.1.2 的 USB 口；
通过 VCC 和 GND 插针直接输入 5V 或者 3.3V 电压，图 1.1.1 和图 1.1.2 都可以通过 VCC 和 GND 供电； (3)、复位：C15 默认不焊，若焊接则延长复位时间；
(4)、TF 卡使用 SPI 方式进行操作，使用时 R1 需焊接 0Ω电阻；
(5)、串行 Flash 使用 SPI0 操作，使用时 R6 需焊接 0Ω电阻；
(6)、LED 指示灯连接 P4.0~P4.3,引脚输出低电平点亮相应的 LED； (7)、P5.4/P5.5 支持 iRS485 数据收发，使用时 R16/R18 焊 20K 电阻，R17 接 120Ω电阻； (8)、外扩 RAM 物理连接采用直接地址方式，用法参考例程 XBUS.C，使用时需短接 J4；

## 2、评估板资料包说明

来源：www.wch.cn 搜索 CH559
文件名：CH559EVT.ZIP
资料包：
头文件（C、汇编）
评估板原理图
PCB 图
例程
2.1 CH559.uvproj
功能：CH559 keil4 工程文件,头文件、延时函数、串口 0 初始化等常用函数定义； 2.2 ADC 文件夹
功能：ADC 中断(查询)方式手动和自动采集，ADC 采样时钟设置，电压比较功能函数定义； 2.3 CHIP_ID 文件夹

功能：芯片唯一 ID 号获取函数定义；
2.4 DataFlash 文件夹
功能：DataFlash 擦除读写函数定义；
2.5 Encryption 文件夹
功能：芯片常用加密方法介绍和说明；
2.6 GPIO 文件夹
功能：GPIO 设置和 GPIO 中断使用说明；
2.7 IAP 文件夹
功能：CH559 用户程序跳转至 IAP 升级演示和说明文档，提供上位机软件和源码； 2.8 LED_CTRL 文件夹
功能：CH559LED 控制卡演示，支持 U 盘更新显示内容和掉电数据不丢失； 2.9 PWM 文件夹
功能：PWM1&2 初始化，PWM 占空比设置函数；
2.10 SPI0 文件夹
功能：SPI0 主机从机模式初始化和数据收发演示，主机操作 CH376，从机连接其他 C51 MCU; 2.11 SPI1 文件夹
功能：SPI0 主机模式初始化和数据收发演示，主机操作 CH376;
2.12 Timer0 文件夹
功能：定时器 0 初始化和定时器、计数器使用函数定义； 2.13 Timer1 文件夹
功能：定时器 1 初始化和定时器、计数器使用函数定义；
2.14 Timer2 文件夹
功能：定时器 2 初始化和定时器、计数器使用函数定义，定时器 2 捕捉功能函数定义；
2.15 Timer3 文件夹
功能：定时器 3 初始化和定时器、计数器使用函数定义，定时器 3 捕捉功能函数定义和 PWM3 设置及使用； 2.16 UART0 文件夹
功能：串口 0 初始化和中断收发示例；
2.17 WDOG 文件夹
功能：看门狗初始化和喂狗；
2.18 XBUS 文件夹
功能：并行总线初始化和数据收发函数定义；
2.19 USB_LIB 文件夹
功能：USB 文件系统库；
2.20 USB 文件夹
A．DEVICE 文件夹
模拟 USB 键鼠例程，支持部分类命令；
模拟厂商自定义设备，需要安装 CH372 驱动，可以通过 372test.exe 调试(批量数据收发，中断传输)； B．HOST 文件夹
USB 主机应用例子,初始化和枚举 USB 端口连接的设备,支持一级外部 HUB,可以操作 USB 键鼠和 HUB，打 印机,包含 HID 类命令处理；
C．U_DISK
字节方式读写文件，包括文件创建、删除、修改文件属性,修改文件名； 扇区方式读写文件，包括文件创建、删除、修改文件属性,修改文件名； 创建文件夹和文件创建；
枚举根目录或者指定目下的文件；
2.21 PUB 评估板说明

功能：评估板说明、评估板原理图

## 3、MCU ISP 下载软件说明

3.1 下载前准备

3.1.1 ISP 变更
重要：因为 ISP 工具升级更新，芯片 BOOT 版本 V2.30 以前的版本需要在 V2.40 及以上版本 ISP 工具上选 择支持的 BOOT 版本，以下以 ISPTool（V2.40）为例，默认支持最新 BOOT。
USB 方式下载：无需任何设置，完全兼容。
串口方式下载：如果不知道具体的 BOOT 版本，请咨询技术人员或者销售人员。
BOOT 版本 ＜ V2.30,设置如图 | ，勾选代表设置成功，如果设置成功，ISP 软件名称显
示如： | 。
BOOT 版本 ≥ V2.30，设置如图 | 。

3.1.2 USB 下载
a.根据 1.2 的（1）选择芯片供电电压；
b.按住 | ，将 USB Host/Device 口与 PC 连接；

c.松开 Download 键；
d．使用 ISP 软件下载，具体参考 3.3 的（1）；
3.1.3 串口下载
a. 根据 1.2 的（1）选择芯片供电电压；
b.串口下载使用芯片的 P02（RXD）和 P03（TXD）引脚，将 TXD，RXD 和 GND 与电脑串口连接；
d. （1）按键下载：按住 | ，通过 USB Host/Device 口与 PC 连接供电，松开按键；

（2）无按键下载：ISP 工具选择串口号，点击下载，然后通过 USB Host/Device 口连接 PC 供电；
e. 使用 ISP 软件下载，具体参考 3.3 的（2）；
软件：需安装 WCHISPToolISP 工具，USB 驱动包含在安装包内，设备上电后会自动安装。 网上下载链接：http://wch.cn/download/WCHISPTool_Setup_exe.html
3.2 ISP 软件功能说明
WCHISPToolISP 软件主要功能：
1.通过 USB 接口对 CH559 进行单个下载或一次多个的批量下载或校验； 2.串口对 CH559 进行单个下载或者指定间隔时间的逐个下载校验； 3.EEPROM 的读写；
4.支持 HEX 或 BIN 格式下载；
4.支持界面初始设置的保存和文件导入；

5.支持下载统计显示，操作记录保存至指定文件内；
6.USB 下载方式下，支持设备动态插拔；
7.ISP 软件支持简体中文和英文；

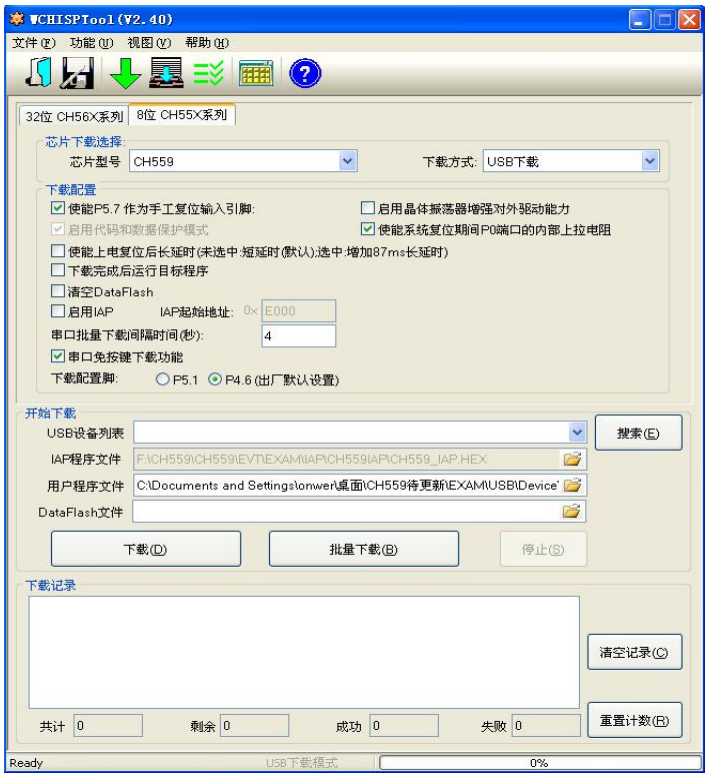
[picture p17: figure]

图 3.1.1 运行 WCHISPTool.exe 主界面

3.3 软件使用说明
(1)、USB 方式下载 MCU 程序：
a.选择芯片系列：点击“8 位 CH55X 系列”标签页面，如 | ；
b.选择芯片型号：在“芯片型号”列表中选择 “CH559”，如 | ；
c.选择下载方式：在“下载方式”列表中选择“USB 下载”，如 | ；

d.下载配置：在“下载配置”栏内，对下载配置进行设置；

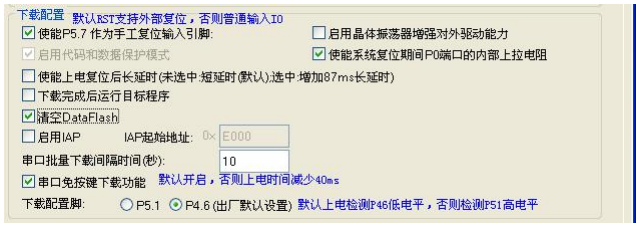
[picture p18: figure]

e.选择下载设备：可以在“USB 设备列表”中选择指定的设备； 如果设备连至 PC，软件检测到，会出现如下图 3.2“USB 列表”显示“型
号 CH559……1 号设备”；
如果没有检测到设备插入，可查看芯片电源连接是否正常，USB 是否连接好等；

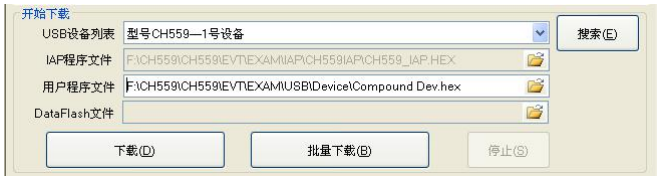
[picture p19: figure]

图 3.3.1
f.选择下载文件：如下载配置中未启用 IAP，只需为 “用户程序文件”选择对应的下载文件； 如启用 IAP ，需为“IAP 程序文件”和“用户程序文件”选择对应的下载 文件；
g.单个下载：点击“下载(D)”按钮进行单个设备的下载
批量下载：如下载类型为“USB 下载”，点击“批量下载 (B)”按钮，会同时对多个设备 进行下载；
如下载类型为“串口下载”，点击“批量下载 (B)”按钮，根据“串口批量下 载间隔时间”,如图 3.5；
来检测设备的接入后自动进行下载，直至点击“停止(S)”按钮结束批量下载； h.如果下载配置中选中“下载完成后自动运行程序”，则 MCU 会在下载完后自退出下载模式，自动加载 运行用户程序；如果未选中，则需要手工给硬件复位或重上电，加载运行用户程序。 i.下载结束，软件会在“下载记录”栏显示当前下载状态，下载成功如图 3.3.2；

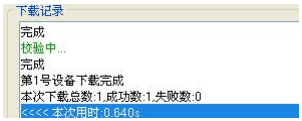
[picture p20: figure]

图 3.3.2
(2)、串口下载 MCU 程序：
a.选择芯片系列：点击“8 位 CH55X 系列”标签页面； b.选择芯片型号：在“芯片型号”列表中选择 “CH559”； c.选择下载方式：在“下载方式”列表中选择“串口下载”； d.下载配置：在“下载配置”栏内，对下载配置进行设置； e.选择下载设备：可以在“串口设备列表”中选择与评估板相连的串口号：

图 3.3.3
f.选择下载文件：如未启用 IAP，只需为 “用户程序文件”选择对应的下载文件； 如启用 IAP ，需为“IAP 程序文件”和“用户程序文件”选择对应的下载 文件；
g.单个下载：点击“下载(D)”按钮进行单个设备的下载 批量下载：如下载类型为“串口下载”，点击“批量下载 (B)”按钮，根据“串口批量下 载间隔时间来检测设备的接入后自动进行下载，直至点击“停止(S)”按钮结束批量下载； 检测设备插入的间隔时间，

图 3.3.4
h.如果选中“下载完成后自动运行程序”，则 MCU 会自退出下载模式，自动加载运行用户程序；如果未 选中，则需要手工给硬件重上电后，加载运行用户程序。
i.下载结束，软件会在“下载记录”栏显示当前下载状态，下载成功如图 3.3.5；

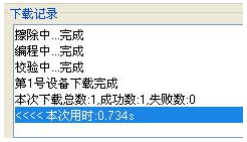
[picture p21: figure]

图 3.3.5
(3)、MCU 程序校验：
a.执行 ISP 下载步骤 a、b、c、d、e、f;
b.点击标题栏上的 | 图标或菜单栏的“功能”->“校验”按钮进行 MCU 烧录代码和指定的“用户

程序文件”进行对比，“下载配置”的设置与 MCU 烧录时的配置进行对比。
(4)、MCU 内置 EEPROM 读写
a.执行 ISP 下载步骤 a、b
b.点击 | 图标，在弹出的“DataFlash”窗口内进行 EEPROM 的读写和保存操作；

（5）、ISP 工具选择语言界面

(6)、 ISP 工具配置保存

a.ISP 工具支持保存配置功能，该功能支持将当前 ISP 工具的配置保存，生成 | 配置文件，
目录可以自己制定，默认和 ISP 工具在同一目录下。

b.ISP 工具支持将 a 保存的配置导入，默认搜索 ISP 工具安装目录下的后缀.INI 文件，将 ISP 工具设置成 保存的配置。

c.恢复默认配置。

## 4、创建工程-编译工具 KEIL

4.1 运行编译器

点击“Project”,如下图选择“New μVision Project…”,弹出一对话框，如下图 3.1.1 所示，选择创建 工程的目录，输入文件名，点击“保存”。

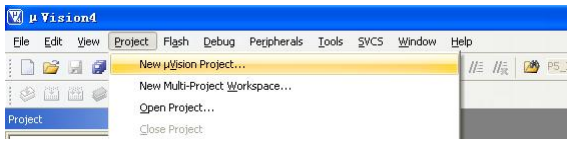
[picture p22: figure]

图 4.1.1
4.2 MCU 器件库添加与选择
(1)、打开 WCHISPTool（V2.6 及以上版本），选择功能→添加 WCH MCU 到 KEIL 器件库。如图 4.2.1 所示。 此时软件会提示“WCH MCU 库添加成功”即可（如图 4.2.2）。

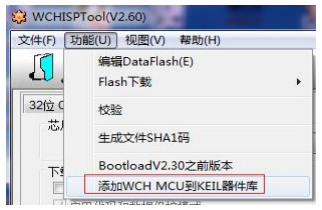
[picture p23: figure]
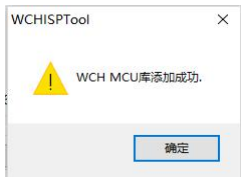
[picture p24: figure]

图 4.2.1 | 图 4.2.2
(2)、打开 Keil C51 工具，创建工程项目。按图 4.2.3 所示 1~3 选择 CH554 芯片。确定后，弹出图 4.2.4 所示窗口，点击“否”即可。

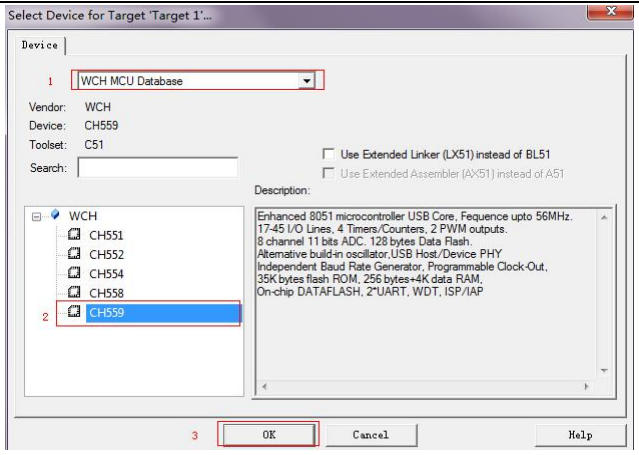
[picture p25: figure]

图 4.2.3

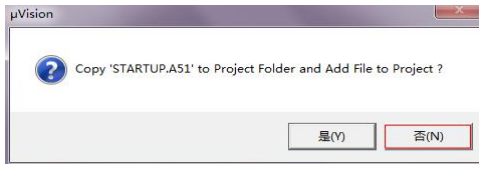
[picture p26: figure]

图 4.2.4
4.3 文件添加
(1)、工程文件打开或者创建完成后，需要添加或者新建程序文件(.C 或者.ASM)，如下图，右击“Source Group1”选择“Add Files To Group ‘Source Group1’”

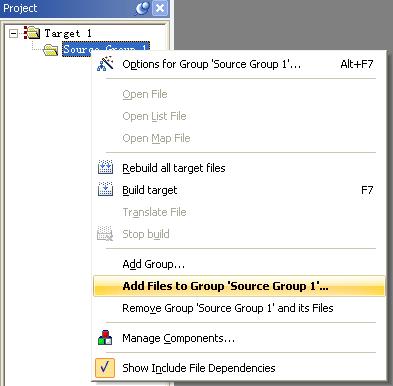
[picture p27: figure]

图 4.3.1
(2)、找到.C 或者.ASM 文件所在目录，选择文件，点击“Add”添加进工程。

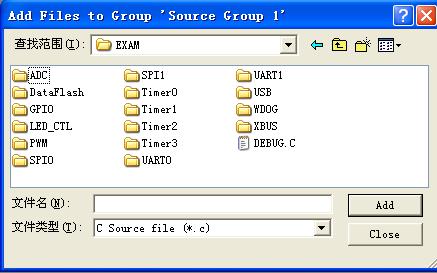
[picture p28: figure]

图 4.3.2

3.4 编译

点击 | ，出现图 4.4.1，勾选“Create HEX File”，点击“OK”，按 F7 或者 | 编译，生成“.HEX”
的文件。

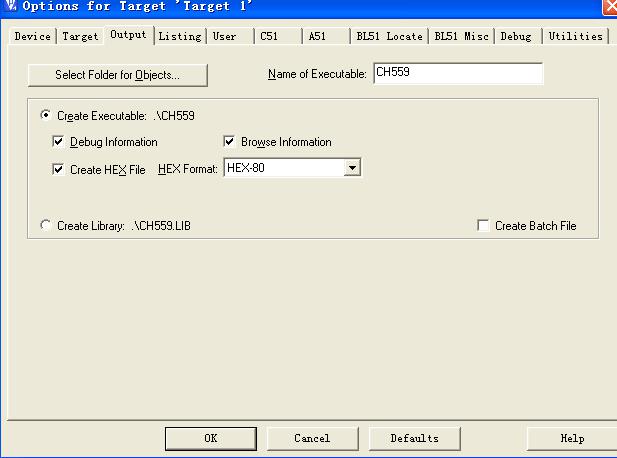
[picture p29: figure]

图 4.4.1

## 5、修改记录

版本 | 日期 | 说明
V1.0 | 2015.5.27 | 初版发行
V1.1 | 2015.10.16 | 1.增加 CH559MINIEVT 的评估板说明； 2.下载说明部分重新调整； 3.增加 IAP 程序下载说明；
V1.2 | 2016.12.08 | 1.增加 CH559MINIEVTV13 的评估板说明； 2.ISP 增加串口批量烧录功能；
V1.3 | 2017.03.06 | 1.ISP 工具升级，下载说明步骤调整；

2.增加 EVT 资料说明；
V1.4 | 2018.02.28 | 1.ISP 工具升级，修改使用说明；
V1.5 | 2018.07.30 | 1.添加 CH55x 设备器件库以及器件选择

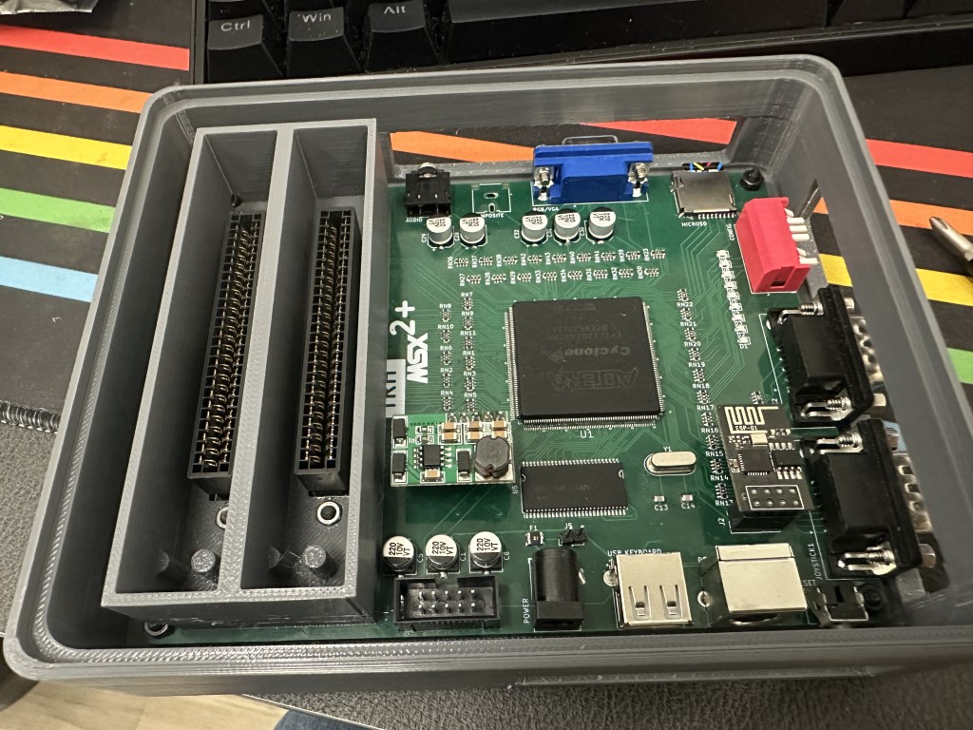
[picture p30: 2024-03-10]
images/20240229_213756238_iOS (Medium).jpg

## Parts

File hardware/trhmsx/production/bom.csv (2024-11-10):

Designator | Footprint | Quantity | Value | LCSC Part #
C1, C28, C29, C30, C31, C32, C5, C8 | CP_Elec_6.3x3 | 8 | 220uF
C10, C11, C12, C15, C16, C17, C18, C19, C2, C20, C21, C22, C23, C24, C3, C4, C6, C7, C9 | 0805 | 19 | 0.1uF
C13, C14 | 0805 | 2 | 27pF
C25 | 0805 | 1 | 2.2uF
C26, C27 | 0805 | 2 | 4.7uF
C33, C34 | 0805 | 2 | 3.3uF
C35 | 0805 | 1 | 10uF
D1, D10, D2, D3, D4, D5, D6, D7, D8, D9 | 0805 | 10 | LED3
F1 | 1210 | 1 | Fuse
J1 | PinSocket_1x05_P2.54mm_Vertical | 1 | MODULE-12V
J10 | DSUB-9_Male_Horizontal_P2.77x2.84mm_EdgePinOffset4.94mm_Housed_MountingHolesOffset7.48mm | 1 | JOY2
J11 | PJ-307 | 1 | AudioJack2_Ground
J13 | TE_5530841-5 | 1 | CART2
J14 | DSUB-15-HD_Female_Horizontal_P2.29x1.98mm_EdgePinOffset3.03mm_Housed_MountingHolesOffset4.94mm | 1 | DH15
J15 | DSUB-9_Male_Horizontal_P2.77x2.84mm_EdgePinOffset4.94mm_Housed_MountingHolesOffset7.48mm | 1 | JOY1
J16 | TE_5530841-5 | 1 | CART1
J17, J5 | PinHeader_1x02_P2.54mm_Vertical | 2 | Conn_01x02
J18 | CUI_MD-40SM | 1 | S-Video
J2 | PinSocket_2x04_P2.54mm_Vertical | 1 | ESP-01
J3 | BarrelJack_Horizontal | 1 | Barrel_Jack
J4 | Conn_uSDcard | 1 | MICRO-SD
J6 | TE_6364372-2 | 1 | KEYBOARD-USB
J7 | TE_5749180-1 | 1 | KEYBOARD-PS2
J8 | PinHeader_2x05_P2.54mm_Vertical | 1 | Conn_02x05_Odd_Even
R1, R2 | 0805 | 2 | 10K
R10 | 0805 | 1 | 22
R11 | 0805 | 1 | 1M
R12, R5 | 0805 | 2 | 1K
R13, R14 | 0805 | 2 | 2.2K
R3, R7 | 0805 | 2 | 10
R8, R9 | 0805 | 2 | 100
RN1, RN10, RN11, RN13, RN14, RN15, RN16, RN19, RN2, RN20, RN21, RN22, RN23, RN3, RN36, RN37, RN38, RN39, RN4, RN40, RN41, RN42, RN43, RN5, RN6, RN7, RN8, RN9 | R_Array_Convex_4x0603 | 28 | 100
RN12, RN25, RN26, RN35, RN44 | R_Array_Convex_4x0603 | 5 | 10K
RN17, RN18, RN24 | R_Array_Convex_4x0603 | 3 | 1K
RN27, RN28, RN29, RN30, RN31, RN32, RN33, RN34 | R_Array_Convex_4x0603 | 8 | 200
SW1 | SW_DIP_SPSTx08_Piano_10.8x21.88mm_W7.62mm_P2.54mm | 1 | SW_DIP_x08
SW2 | SW_Tactile_SPST_Angled_PTS645Vx83-2LFS | 1 | SW_Push
SW3 | SW_Push_1P1T_NO_6x6mm_H9.5mm | 1 | SW_Push
U1 | QFP50P3460X3460X410-240N | 1 | EP1C12Q240C8N | EP1C12Q240C8N
U2 | SOT-223-3_TabPin2 | 1 | AMS1117-1.5
U3 | SOT-223-3_TabPin2 | 1 | AMS1117-3.3
U4 | SOT65P210X110-6N | 1 | NC7WZU04P6X
U5 | TSOP-II-54_22.2x10.16mm_P0.8mm | 1 | MT48LC16M16A2TG
U6 | SO08 | 1 | M51953BFP
U7 | SSOP-20_5.3x7.2mm_P0.65mm | 1 | CH559T
U8 | SO08 | 1 | EPCS4
Y1 | Crystal_HC49-U_Vertical | 1 | 21.47727 MHz

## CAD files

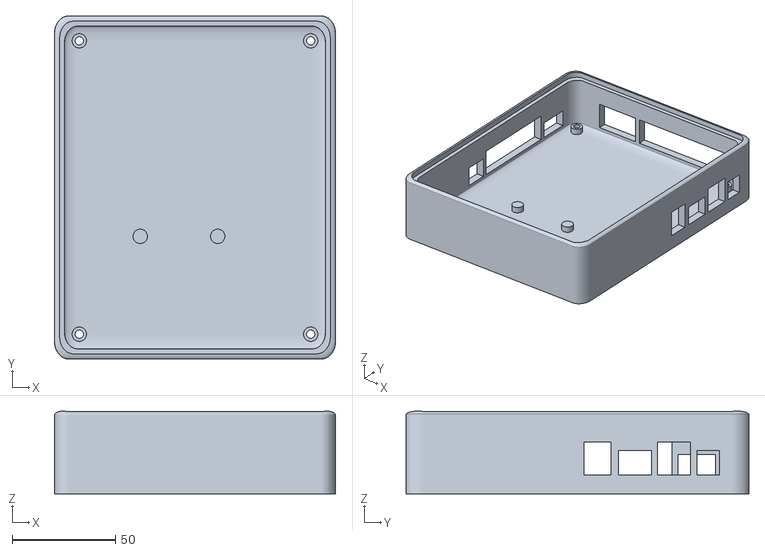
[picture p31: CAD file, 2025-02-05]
case/TRHMSX_case_base_v2.0.stl
136.0 x 166.0 x 40.0

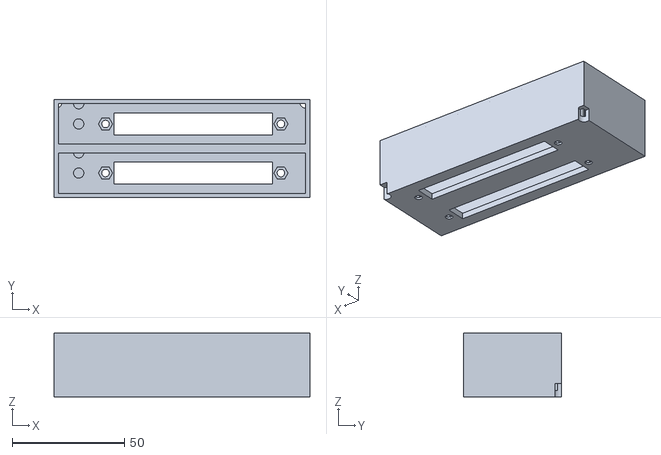
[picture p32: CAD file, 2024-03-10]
case/TRHMSX_cart_guide_v1.4.stl
114.0 x 43.9 x 28.5

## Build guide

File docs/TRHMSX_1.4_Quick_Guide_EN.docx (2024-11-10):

# The Retro Hacker - TRHMSX – Quick User Guide – 1.0

THANK YOU FOR YOUR PURCHASE!

Just like you, I love MSX, and this computer was carefully built in my laboratory for you. I don't make a living by selling these things on the Internet, it's my hobby, and all profits go towards building new projects and keeping the MSX alive.

Please, if you have any issues with the computer, let me know immediately. I want you to have the same experience I desire as a buyer.

This FPGA-based MSX2+ hardware represents a straightforward implementation, drawing inspiration from the original 1chipMSX circuit but featuring several enhancements and a new PCB design for improved functionality.

TRHMSX features:

- MSX2+ Compatibility: Reproducing the MSX2+ architecture, ensuring compatibility with a wide range of software and games.
- Expanded Memory Options: Choose between 2MB or 4MB of mapped RAM, providing flexibility for diverse computing needs and applications.
- 9958 Video Display Processor (VDP): Incorporating the 9958 VDP for sharp graphics and improved visual performance, delivering an authentic MSX experience.
- FM and SCC Sound Capabilities: Featuring FM synthesis and SCC sound to reproduce the iconic audio characteristics of MSX systems, enhancing the overall gaming and multimedia experience.
- Programmable Sound Generator (PSG): Including the original PSG for standard MSX audio output.
- Keyboard Compatibility: Supporting PS/2 keyboards with the option for USB keyboards, providing users with a choice for their preferred input device.
- MicroSD Card Support: Integrating a microSD card slot for convenient storage and easy access to files, games, and software.
- MSX Cartridge Slots: Equipped with two MSX cartridge slots, allowing users to explore a vast library of MSX cartridges for an extended range of applications and games.
- Dual Joystick Ports: Featuring two joystick ports for multiplayer gaming and compatibility with classic MSX peripherals.
- Wireless Network Support: Incorporating wireless network support through the ESP8266, enabling online connectivity and expanding the possibilities for networked applications.
- 12V Cartridge Lines: Providing dedicated 12V lines for cartridges, ensuring compatibility with a variety of peripherals and accessories.
- MIDI Output: Generates MIDI output over the Joystick Port 2 (needs a custom cable and a MIDI player).

This guide was created to help you get started with setting up and using your new computer. It comes already set up with 2MB of RAM, and with a pre-built microSD card that has MSXDOS 2 and the newest version of SofaRUN ready to go. I've even tossed in some ROM files from my own collection so you can dive right into enjoying your MSX experience from the get-go.

## Power Source

Your computer is equipped with a 5V 2A power source (center positive), which is connected via a 2.1mm jack. It's essential to be cautious if you consider using a different power source, as connecting power sources with higher voltages can potentially harm the computer, leading to the need for repairs. Always stick to using the provided power source or an equivalent one (5V 2A) to ensure the safety and proper functioning of your computer.

## Configuration (Dipswitch)

On the side of your computer, you'll notice an eight-position dipswitch (in red). This handy feature allows you to customize various settings for your TRHMSX. Refer to the table below for a detailed description of each available configuration.

DIP-SW | FUNCTION | OPTION | DESCRIPTION
1 | CPU Clock | OFF | Standard mode 3.58MHz
| | ON | Custom Speed mode 4.10MHz to 8.06MHz (10.74MHz on system bus) • Press [F12] key to change clock type (3.58MHz >> 5.37MHz >> Custom Speed) • The external clock is set on [Sync to CPU] by default • [Turbo Pana] is 5.37MHz like the original specification • A special hybrid clock [Turbo MegaSD] is enabled by default
2/3 | Video Output | OFF/OFF | Composite • 15kHz, 50Hz+60Hz, interlaced video signal
| | OFF/ON | RGB w/ Audio Out (a mono signal inside the video cable) • 15kHz, 50Hz+60Hz, interlaced video signal, requires a VGA to SCART cable
| | ON/OFF | VGA Mode for LED TV or LED Display • Progressive video signal 31kHz / 50Hz+60Hz with the ability to set the pixel ratio 1:1 at 60Hz
| | ON/ON | VGA+ Mode for CRT Monitor (legacy output) • Progressive video signal 31kHz / 50Hz+60Hz / SETSMART -D0 must be executed to force 60Hz
4 | Cartridge Slot-1 | OFF | External Slot-1 • Recommended default
| | ON | Internal ESE-MegaSCC+ 1024kB (shared w/ the 2nd half of ESE-MegaSCC+ Slot-2) • External Slot-1 is disabled • Memo: the CMT toggle is [Scroll Lock] key (disabled by default)
5/6 | Cartridge Slot-2 | OFF/OFF | External Slot-2 • Recommended default
| | OFF/ON | Internal ESE-MegaRAM ASCII-8K 1024kB • External Slot-2 is disabled
| | ON/OFF | Internal ESE-MegaSCC+ 2048kB • External Slot-2 is disabled
| | ON/ON | Internal ESE-MegaRAM ASCII-16K 2048kB • External Slot-2 is disabled
7 | Internal Mapper | OFF | Internal 2048kB RAM • Recommended default
| | ON | Internal 4096kB RAM
8 | Internal microSD | OFF | Disabled
| | ON | Enabled • Recommended like default

By default, your computer is set to 3.58Mhz, generate VGA video with 31Khz, enable the microSD card, and have 2 MB of RAM. If you wish to modify these configurations, simply adjust the positions of the corresponding dip switches accordingly. The default position of each dip switch is shown in gray.

Video Output

By default, your computer is configured for VGA video output at 31Khz (dip switches 2/3 in ON/OFF), which provides the best video quality for the TRHMSX. This configuration is strongly recommended. The VGA standard is supported by most LED/LCD displays with a DH15 connector. For screens that only support HDMI, you can use an inexpensive VGA-to-HDMI converter to achieve optimal results.

The composite video output is offered just for compatibility with older screens and doesn’t offer the best quality. The circuit to equalize the VB_CV signal has been removed for simplicity. That circuit was also not part of the original 1chipMSX computer, and its absence results in a slight pink tint in text modes and more saturated colors when playing games using composite video. This color distortion is expected without the VB_CV correction circuit.

## Keyboard

The TRHMSX is compatible with PS/2 keyboards, either with native PS/2 connectors or USB connectivity. However, it's important to note that not all USB keyboards are compatible with the TRHMSX; only those implementing the PS/2 protocol over USB are suitable.

Whenever feasible, it is advisable to select native PS/2 keyboards. Should you opt to utilize a USB-connected keyboard, ensure that it can support the PS/2 protocol. Typically, modern mechanical keyboards lack support for this protocol and may not function properly with the TRHMSX. Conversely, older and simpler USB keyboards are more likely to support the PS/2 protocol and integrate effectively with the computer.

There are some keyboard shortcuts that can be used with the TRHMSX, the following table document those:

Key or Key Combination | Function
END | MSX STOP key
ALT | MSX GRAPH key
Windows | Space (when playing games, it is recommended to use the Windows Key to shoot instead of the space to avoid issues with moving object in diagonal)
F6 | MSX GRAPH key
F7 | MSX KANA key
F8 | MSX SELECT key
F9 | Increases PSG volume
SHIFT + F9 | Decreases PSG volume
F10 | Increases SCC volume
SHIFT + F10 | Decreases SCC volume
F11 | Increases OPL volume
SHIFT + F11 | Decreases OPL volume
PAGE UP | Increases overall volume
PAGE DOWN | Decreases overall volume
F12 | Alternates CPU clock in turbo mode: 3.58 Mhz ->5.37 Mhz -> Custom
PRINT SCREEN | Alternates video output mode: VGA 31Khz -> RGB 15Khz -> CVBS
SCROLL LOCK | Activates/Deactivates cassette mode
SHIFT + F12 | Alternates the Slot 1 mode: External -> MegaSCC+ 1024kB
SHIFT + SCROLL LOCK | Alternates the Slot 2 mode: External -> MegaRAM ASCII-8K -> MegaSCC+ 2048kB -> MegaRAM ASCII-16K

## Status Leds

On the printed circuit board, you'll find a bank of LEDs that serve as diagnostic indicators, allowing you to track the performance of your computer and identify potential issues. The table below provides a detailed description of each LED, enabling you to gain a comprehensive understanding of their respective meanings.

LED | Status | Description
1 | Blinking | Activity with the microSD card
2 | OFF | 2MB Memory Mapper
| ON | 4MB Memory Mapper
3/4 | OFF/OFF | External Slot 2 Enabled
| OFF/ON | MegaRAM ASCII 8K Enabled
| ON/OFF | MegaSCC+ Enabled
| ON/ON | MegaRAM ASCII 16K Enabled
5 | OFF | External Slot 1 Enabled
| ON | SCC+ Enabled
6/7 | OFF/OFF | Composite video enabled
| OFF/ON | RGB w/ Audio Out (a mono signal inside the video cable) enabled
| ON/OFF | VGA Mode for LED TV or LED Display enabled
| ON/ON | VGA+ Mode for CRT Monitor (legacy output) enabled
8/9 | OFF/OFF | Standard mode 3.58MHz enabled
| OFF/ON | [Turbo Pana] mode 5.37MHz enabled
| ON/OFF | Custom clock enabled

## MicroSD Card

Your microSD card comes pre-configured with dynamic BIOS and all the necessary files to boot into MSXDOS2. When you power up your TRHMSX with dipswitch 8 enabled, the dynamic BIOS kicks in, seamlessly leading you into the MSXDOS2 environment, where you'll be greeted by the MSXDOS prompt.

Additionally, the card includes SofaRun 8 along with a curated collection of ROM files, providing you with everything you need to start using your computer right away. Simply execute SR8\SR to launch SofaRun and begin exploring the wealth of content at your fingertips.

## Network

By default, your computer comes with Wi-Fi capability enabled, albeit without the necessary network configuration to establish a connection. To initiate the setup process and connect your computer to your local wireless network, you'll need to perform the initial configuration.

To configure your network settings, power on the computer and press F1 during the boot sequence. You'll observe a message confirming the start of the network configuration process. From there, navigate to the appropriate option to configure wireless access. You'll be prompted to select the name of your network (SSID) and its corresponding password to establish a connection.

Following the initial setup, subsequent boot-ups will automatically connect your computer to the designated wireless network.

The jumper that is located close to the ESP8266 enables or disables the network card. You can choose to disable that feature by removing the jumper from the board.

The microSD card had a collection of network tools available on the NETWORK folder. Please explore those programs as they offer you a way to download and use programs obtained from the Internet.

## Tips and Tricks

- If you are going to use disk interfaces, make sure that you enable the external cartridge slots and disable the microSD card as that configuration can interfere with the external disk controller.
- If you want to connect a cassette device, you need to disable the internal microSD drive by changing the dipswitch 8 to OFF. Then turn your computer on and push SCROLL LOCK once. Connect your cassette unit into the audio jack and use the appropriate commands from the basic.

## Solving Basic Issues

### Issue: The TRHMSX doesn't power on.

Is the power cable correctly connected? Is the power source compatible? The TRHMSX needs a power supply of 5V/2A center positive. Do not attempt to power the unit using the USB connector, you may damage the computer.

### Issue: The TRHMSX is powered on but doesn't display anything on the screen.

Is it properly connected to the monitor? Is the connector/cable faulty? Does the appropriate status led light up correctly?

If you cannot get video from a specific connector, try to switch the configuration and connect to another monitor using a different cable/connector. Through combinations of dip switches 2 and 3, you can change the display modes. If the screen doesn't display anything and no hardware issue is detected, check the dip switch settings.

### Issue: The keyboard doesn't work.

Is the keyboard connected to the PS/2 port or the right USB port? Only keyboards compatible with the PS/2 protocol can be used with the TRHMSX. Try another keyboard.

### Issue: The ROM cartridge doesn't work.

Is the cartridge dirty? Clean the cartridge and the slot if the cartridge doesn't work. Some cartridges need to be started with the shift key pressed.

### Issue: The microSD Card is not working.

Is dipswitch 8 turned off? Is the card formatted with FAT16?

### Issue: Joysticks are not working

Is the joystick (gamepad) compatible with MSX?

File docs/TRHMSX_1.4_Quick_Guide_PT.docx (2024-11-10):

# Retro Hacker - TRHMSX - Guia Rápido de Uso - 1.0

OBRIGADO PELA SUA COMPRA! Assim como você, eu amo o MSX, e este computador foi cuidadosamente construído no meu laboratório para você. Não ganho a vida vendendo essas coisas na Internet, é meu hobby, e todos os lucros são direcionados para a construção de novos projetos e para manter o MSX vivo.

Por favor, se tiver algum problema com o computador, me avise imediatamente. Quero que você tenha a mesma experiência que desejo para mim como comprador.

Este hardware MSX2+ baseado em FPGA representa uma implementação direta, inspirada no circuito original do 1chipMSX, mas com várias melhorias e um novo design de PCB para funcionalidade aprimorada.

O TRHMSX oferece:

- Compatibilidade MSX2+: Reproduzindo a arquitetura MSX2+, garantindo compatibilidade com uma ampla gama de software e jogos.
- Opções de Memória Expandida: Escolha entre 2MB ou 4MB de RAM mapeada, proporcionando flexibilidade para diversas necessidades e aplicações computacionais.
- Processador de Exibição de Vídeo 9958 (VDP): Incorporando o VDP 9958 para gráficos nítidos e desempenho visual aprimorado, proporcionando uma experiência MSX autêntica.
- Capacidades de Som FM e SCC: Com síntese FM e som SCC para reproduzir as características de áudio icônicas dos sistemas MSX, aprimorando a experiência geral de jogos e multimídia.
- Gerador de Som Programável (PSG): Incluindo o PSG original para saída de áudio MSX padrão.
- Compatibilidade com Teclado: Suportando teclados PS/2 com opção para teclados USB, proporcionando aos usuários a escolha do dispositivo de entrada preferido.
- Suporte a Cartão MicroSD: Integrando um slot para cartão microSD para armazenamento conveniente e acesso fácil a arquivos, jogos e software.
- Slots de Cartão MSX: Equipado com dois slots de cartucho MSX, permitindo aos usuários explorarem uma vasta biblioteca de cartuchos MSX para uma variedade expandida de aplicativos e jogos.
- Portas de Joystick Duplas: Com duas portas de joystick para jogos multiplayer e compatibilidade com periféricos MSX clássicos.
- Suporte de Rede Sem Fio: Incorporando suporte de rede sem fio através do ESP8266, possibilitando conectividade online e expandindo as possibilidades para aplicativos em rede.
- Linhas de Cartucho de 12V: Fornecendo linhas dedicadas de 12V para cartuchos, garantindo compatibilidade com uma variedade de periféricos e acessórios.
- Saída MIDI: Oferece a capacidade de gerar comandos MIDI através da porta 2 do Joystick (usando um cabo customizado e um tocador de instrumentos MIDI).

Este guia foi criado para ajudá-lo a começar a usar seu novo computador.

Ele já vem configurado com 2MB de RAM e com um cartão microSD pré-construído que possui o MSXDOS 2 e a versão mais recente do SofaRun prontos para uso. Incluí até mesmo alguns arquivos ROM da minha própria coleção para que você possa mergulhar diretamente na experiência MSX desde o início.

## Fonte de Alimentação

Seu computador está equipado com uma fonte de alimentação de 5V 2A (pino central positivo), que é conectada através de um conector de 2,1 mm. É essencial ter cuidado ao considerar o uso de uma fonte de alimentação diferente, pois a conexão de fontes de alimentação com tensões mais altas pode potencialmente danificar o computador, exigindo reparos. Sempre use a fonte de alimentação fornecida ou uma equivalente (5V 2A) para garantir a segurança e o funcionamento adequado do seu computador.

## Configuração (Dipswitch)

Ao lado do seu computador, você notará um dipswitch de oito posições (em vermelho). Este recurso prático permite que você personalize várias configurações para o seu TRHMSX. Consulte a tabela abaixo para uma descrição detalhada de cada configuração disponível.

DIP-SW | FUNCTION | OPTION | DESCRIPTION
1 | CPU Clock | OFF | Standard mode 3.58MHz
| | ON | Custom Speed mode 4.10MHz to 8.06MHz (10.74MHz on system bus) • Press [F12] key to change clock type (3.58MHz >> 5.37MHz >> Custom Speed) • The external clock is set on [Sync to CPU] by default • [Turbo Pana] is 5.37MHz like the original specification • A special hybrid clock [Turbo MegaSD] is enabled by default
2/3 | Video Output | OFF/OFF | Composite • 15kHz, 50Hz+60Hz, interlaced video signal
| | OFF/ON | RGB w/ Audio Out (a mono signal inside the video cable) • 15kHz, 50Hz+60Hz, interlaced video signal, requires a VGA to SCART cable
| | ON/OFF | VGA Mode for LED TV or LED Display • Progressive video signal 31kHz / 50Hz+60Hz with the ability to set the pixel ratio 1:1 at 60Hz
| | ON/ON | VGA+ Mode for CRT Monitor (legacy output) • Progressive video signal 31kHz / 50Hz+60Hz / SETSMART -D0 must be executed to force 60Hz
4 | Cartridge Slot-1 | OFF | External Slot-1 • Recommended default
| | ON | Internal ESE-MegaSCC+ 1024kB (shared w/ the 2nd half of ESE-MegaSCC+ Slot-2) • External Slot-1 is disabled • Memo: the CMT toggle is [Scroll Lock] key (disabled by default)
5/6 | Cartridge Slot-2 | OFF/OFF | External Slot-2 • Recommended default
| | OFF/ON | Internal ESE-MegaRAM ASCII-8K 1024kB • External Slot-2 is disabled
| | ON/OFF | Internal ESE-MegaSCC+ 2048kB • External Slot-2 is disabled
| | ON/ON | Internal ESE-MegaRAM ASCII-16K 2048kB • External Slot-2 is disabled
7 | Internal Mapper | OFF | Internal 2048kB RAM • Recommended default
| | ON | Internal 4096kB RAM
8 | Internal microSD | OFF | Disabled
| | ON | Enabled • Recommended like default

Por padrão, seu computador está configurado para 3,58 MHz, gera vídeo VGA com 31 kHz, habilita o cartão microSD e possui 2 MB de RAM. Se desejar modificar essas configurações, simplesmente ajuste as posições dos dip switches correspondentes conforme necessário. A posição padrão de cada dip switch é mostrada em cinza na tabela acima.

## Saída de Vídeo

Por padrão, seu computador está configurado para saída de vídeo VGA a 31Khz (chaves DIP 2/3 em ON/OFF), o que proporciona a melhor qualidade de vídeo para o TRHMSX. Esta configuração é fortemente recomendada. O padrão VGA é suportado pela maioria dos monitores LED/LCD com conector DH15. Para telas que suportam apenas HDMI, você pode usar um conversor simples VGA-para-HDMI (VGA2HDMI).

A saída de vídeo composto é oferecida apenas para compatibilidade com telas mais antigas e não oferece a melhor qualidade. O circuito para equalizar o sinal VB_CV foi removido por simplicidade. Esse circuito também não fazia parte do computador 1chipMSX original, e sua ausência resulta em um leve tom rosa nos modos de texto e cores mais saturadas ao jogar usando vídeo composto. Essa distorção de cor é esperada sem o circuito de correção VB_CV.

## Teclado

O TRHMSX é compatível com teclados PS/2, seja com conectores PS/2 nativos ou USB. No entanto, é importante observar que nem todos os teclados USB são compatíveis com o TRHMSX; apenas aqueles que implementam o protocolo PS/2 sobre USB são adequados.

Sempre que possível, é aconselhável selecionar teclados PS/2 com conectores nativos. Se optar por utilizar um teclado USB, certifique-se de que ele suporte o protocolo PS/2. Normalmente, teclados mecânicos modernos não possuem suporte para esse protocolo e podem não funcionar corretamente com o TRHMSX. Por outro lado, teclados USB mais antigos e simples são mais propensos a oferecer suporte ao protocolo PS/2 e integrar-se efetivamente ao computador.

Existem alguns atalhos de teclado que podem ser usados com o TRHMSX, a tabela a seguir os documenta:

Key or Key Combination | Function
END | MSX STOP key
ALT | MSX GRAPH key
Windows | Space (when playing games, it is recommended to use the Windows Key to shoot instead of the space to avoid issues with moving object in diagonal)
F6 | MSX GRAPH key
F7 | MSX KANA key
F8 | MSX SELECT key
F9 | Increases PSG volume
SHIFT + F9 | Decreases PSG volume
F10 | Increases SCC volume
SHIFT + F10 | Decreases SCC volume
F11 | Increases OPL volume
SHIFT + F11 | Decreases OPL volume
PAGE UP | Increases overall volume
PAGE DOWN | Decreases overall volume
F12 | Alternates CPU clock in turbo mode: 3.58 Mhz ->5.37 Mhz -> Custom
PRINT SCREEN | Alternates video output mode: VGA 31Khz -> RGB 15Khz -> CVBS
SCROLL LOCK | Activates/Deactivates cassette mode
SHIFT + F12 | Alternates the Slot 1 mode: External -> MegaSCC+ 1024kB
SHIFT + SCROLL LOCK | Alternates the Slot 2 mode: External -> MegaRAM ASCII-8K -> MegaSCC+ 2048kB -> MegaRAM ASCII-16K

## LEDs de Status

Na placa de circuito impresso, você encontrará um banco de LEDs que servem como indicadores de diagnóstico, permitindo que você acompanhe o desempenho do seu computador e identifique possíveis problemas. A tabela abaixo fornece uma descrição detalhada de cada LED, permitindo que você obtenha uma compreensão abrangente de seus respectivos significados.

LED | Status | Description
1 | Blinking | Activity with the microSD card
2 | OFF | 2MB Memory Mapper
| ON | 4MB Memory Mapper
3/4 | OFF/OFF | External Slot 2 Enabled
| OFF/ON | MegaRAM ASCII 8K Enabled
| ON/OFF | MegaSCC+ Enabled
| ON/ON | MegaRAM ASCII 16K Enabled
5 | OFF | External Slot 1 Enabled
| ON | SCC+ Enabled
6/7 | OFF/OFF | Composite video enabled
| OFF/ON | RGB w/ Audio Out (a mono signal inside the video cable) enabled
| ON/OFF | VGA Mode for LED TV or LED Display enabled
| ON/ON | VGA+ Mode for CRT Monitor (legacy output) enabled
8/9 | OFF/OFF | Standard mode 3.58MHz enabled
| OFF/ON | [Turbo Pana] mode 5.37MHz enabled
| ON/OFF | Custom clock enabled

## Cartão MicroSD

Seu cartão microSD vem pré-configurado com um BIOS dinâmico que suporta rede wireless e todos os arquivos necessários para inicializar no MSXDOS2. Quando você liga seu TRHMSX com o dipswitch 8 habilitado, você será recebido pelo prompt MSXDOS.

Além disso, o cartão inclui o SofaRun 8 junto com uma coleção selecionada de arquivos ROM, fornecendo tudo o que você precisa para começar a usar seu computador imediatamente. Basta executar SR8\SR para iniciar o SofaRun e começar a explorar o conteúdo.

## Rede

Por padrão, seu computador vem com a capacidade Wi-Fi habilitada, embora sem a configuração de rede necessária para estabelecer uma conexão.

Para iniciar o processo de configuração e conectar seu computador à sua rede sem fio local, você precisará realizar a configuração inicial. Para configurar sua rede, ligue o computador e pressione F1 durante a sequência de inicialização.

Você observará uma mensagem confirmando o início do processo de configuração de rede. A partir daí, navegue até a opção apropriada para configurar o acesso sem fio. Você será solicitado a selecionar o nome de sua rede (SSID) e sua senha correspondente para estabelecer uma conexão.

Após a configuração inicial, inicializações subsequentes conectarão automaticamente seu computador à rede sem fio designada.

O jumper que está localizado próximo ao ESP8266 habilita ou desabilita o cartão de rede. Você pode optar por desativar esse recurso removendo o jumper da placa.

O cartão microSD possui uma coleção de ferramentas de rede disponíveis na pasta NETWORK. Por favor, explore esses programas, pois eles oferecem uma maneira de baixar e usar programas obtidos da Internet, dentre outras coisas.

## Dicas e Truques

- Se você pretende usar interfaces de disco, certifique-se de habilitar os slots de cartão externos e desativar o cartão microSD, pois essa configuração pode interferir no controlador de disco externo.
- Se deseja conectar um dispositivo de cassete, você precisa desabilitar o drive microSD interno mudando o dipswitch 8 para OFF. Em seguida, ligue o computador e pressione SCROLL LOCK uma vez. Conecte sua unidade de cassete na entrada de áudio e use os comandos apropriados do BASIC.

## Resolução de Problemas Básicos

### Problema: O TRHMSX não liga.

O cabo de energia está corretamente conectado? A fonte de alimentação é compatível? O TRHMSX precisa de uma fonte de alimentação de 5V/2A com pino central positivo. Não tente ligar a unidade usando o conector USB, você pode danificar o computador.

### Problema: O TRHMSX está ligado, mas não exibe nada na tela.

Está corretamente conectado ao monitor? O conector/cabo está com defeito? O LED de status apropriado acende corretamente?

Se você não conseguir obter vídeo de um conector específico, tente alternar a configuração e conectar a outro monitor usando um cabo/conector diferente. Através de combinações de dip switches 2 e 3, você pode alterar os modos de exibição. Se a tela não mostrar nada e nenhum problema de hardware for detectado, verifique as configurações dos dip switches.

### Problema: O teclado não funciona.

O teclado está conectado à porta PS/2 ou à porta USB correta? Apenas teclados compatíveis com o protocolo PS/2 podem ser usados com o TRHMSX. Experimente outro teclado.

### Problema: O cartucho ROM não funciona.

O cartucho está sujo? Limpe o cartucho e o slot se o cartucho não funcionar. Alguns cartuchos precisam ser iniciados com a tecla shift pressionada.

### Problema: O cartão microSD não está funcionando.

O dipswitch 8 está desativado? O cartão está formatado com FAT16?

### Problema: Os joysticks não estão funcionando

O joystick (gamepad) é compatível com MSX?

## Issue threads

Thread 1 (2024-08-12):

case top cover and transfluent one

serperus, 2024-08-12:
Hi Cristiano!
Thanks for the great project :)
Could you please look at the cover for 3d printing? Seems the cart slot is a bit out of place.

Thanks!
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

cristianoag, 2024-11-01:
Hi @serperus, I've cut that cover with my laser multiple times without any issues. Could you clarify what you mean by "out of place"?

cristianoag, 2024-11-01:
I just cut another piece on the laser, and that part measures 11mm, not 6.5mm. I also double-checked the project file, and it’s correct. It might be a conversion issue between inches and centimeters.
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

serperus, 2024-11-01:
Hi Cristiano,
Yes, yor measurement is correct.
Printed this cover:

https://github.com/cristianoag/trhmsx/blob/main/case/TRHMSX_Translucent_Cover.stl at jlc3d and got 6,5mm where you have 11mm.

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

Have no idea what goes wrong.
Thank you
Serge

cristianoag, 2024-11-01:
Got it. Yeah, my fault.. sorry. I usually cut that cover in transparent acrylic and for that I use LightBurn and the .lbrn2 file. Just fixed the cover. Sorry... you will need to print it again. :( I recommend doing that with translucent filament or transparent resin.

serperus, 2024-11-01:
It's ok, will print it once more.
Thank you!

Closed 2024-11-15.

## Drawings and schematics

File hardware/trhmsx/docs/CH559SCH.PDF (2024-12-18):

# CH558&9 T&L MINIEVT 评估板原理图：

# CH559L/CH558L USB

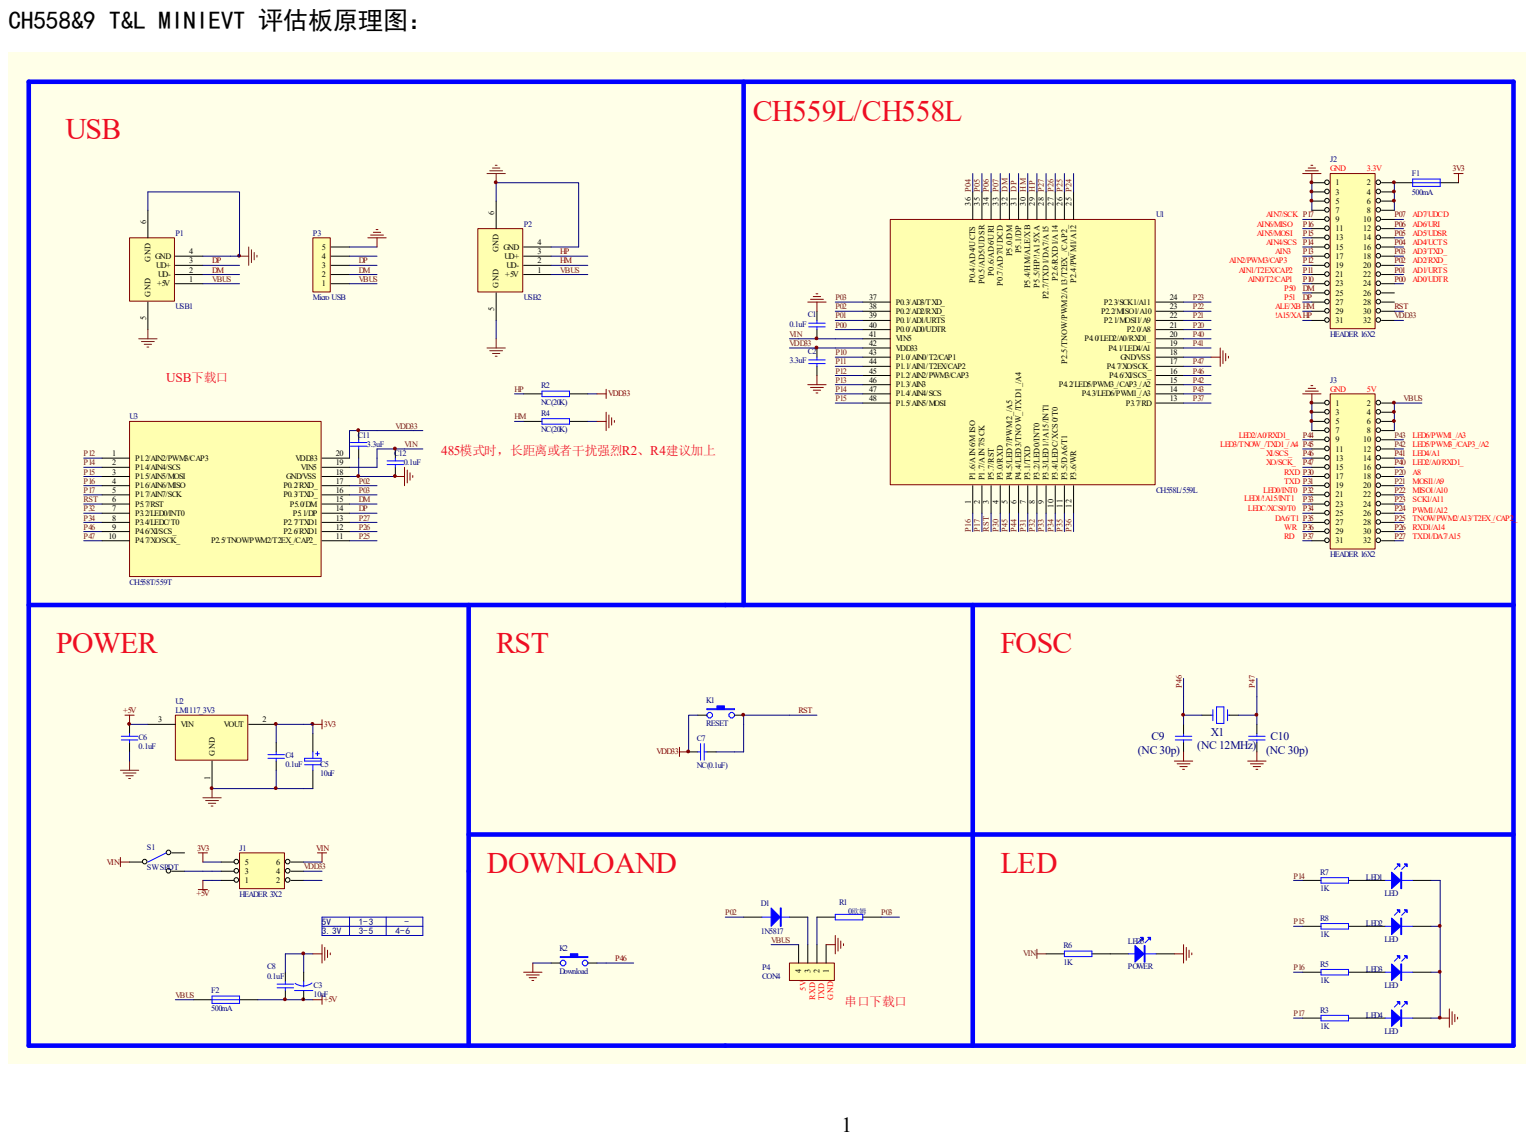
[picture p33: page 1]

9 P3.4/LEDC/XCS0/T0 10 P3.5/DA6/T1 11 P3.6/WR 12 P3.7/RD 13 P4.6/XI/SCS_ 16 P4.7/XO/SCK_ 17 GND/VSS 18 P4.0/LED2/A0/RXD1_ 20 P2.0/A8 21 P2.1/MOSI1/A9 22 P2.2/MISO1/A10 23 P2.3/SCK1/A11 24 P2.4/PWM1/A12 25 P2.5/TNOW/PWM2/A13/T2EX_/CAP2_ 26 P2.6/RXD1/A14 27 P2.7/TXD1/DA7/A15 28 P5.5/HP/!A15/XA 29 P5.4/HM/ALE/XB 30 P5.1/DP 31 P5.0/DM 32 P0.7/AD7/UDCD 33 P0.6/AD6/URI 34 P0.5/AD5/UDSR 35 P0.4/AD4/UCTS 36 P0.3/AD3/TXD_ 37 P0.2/AD2/RXD_ 38 P0.1/AD1/URTS 39 P0.0/AD0/UDTR 40 VIN5 41 VDD33 42 P1.0/AIN0/T2/CAP1 43 P1.1/AIN1/T2EX/CAP2 44 P1.2/AIN2/PWM3/CAP3 45 P1.3/AIN3 46 P1.4/AIN4/SCS 47 P4.3/LED6/PWM1_/A3 14 P4.2/LED5/PWM3_/CAP3_/A2 15 P4.5/LED7/PWM2_/A5

5V | 1-3 | -
3. 3V

# POWER RST

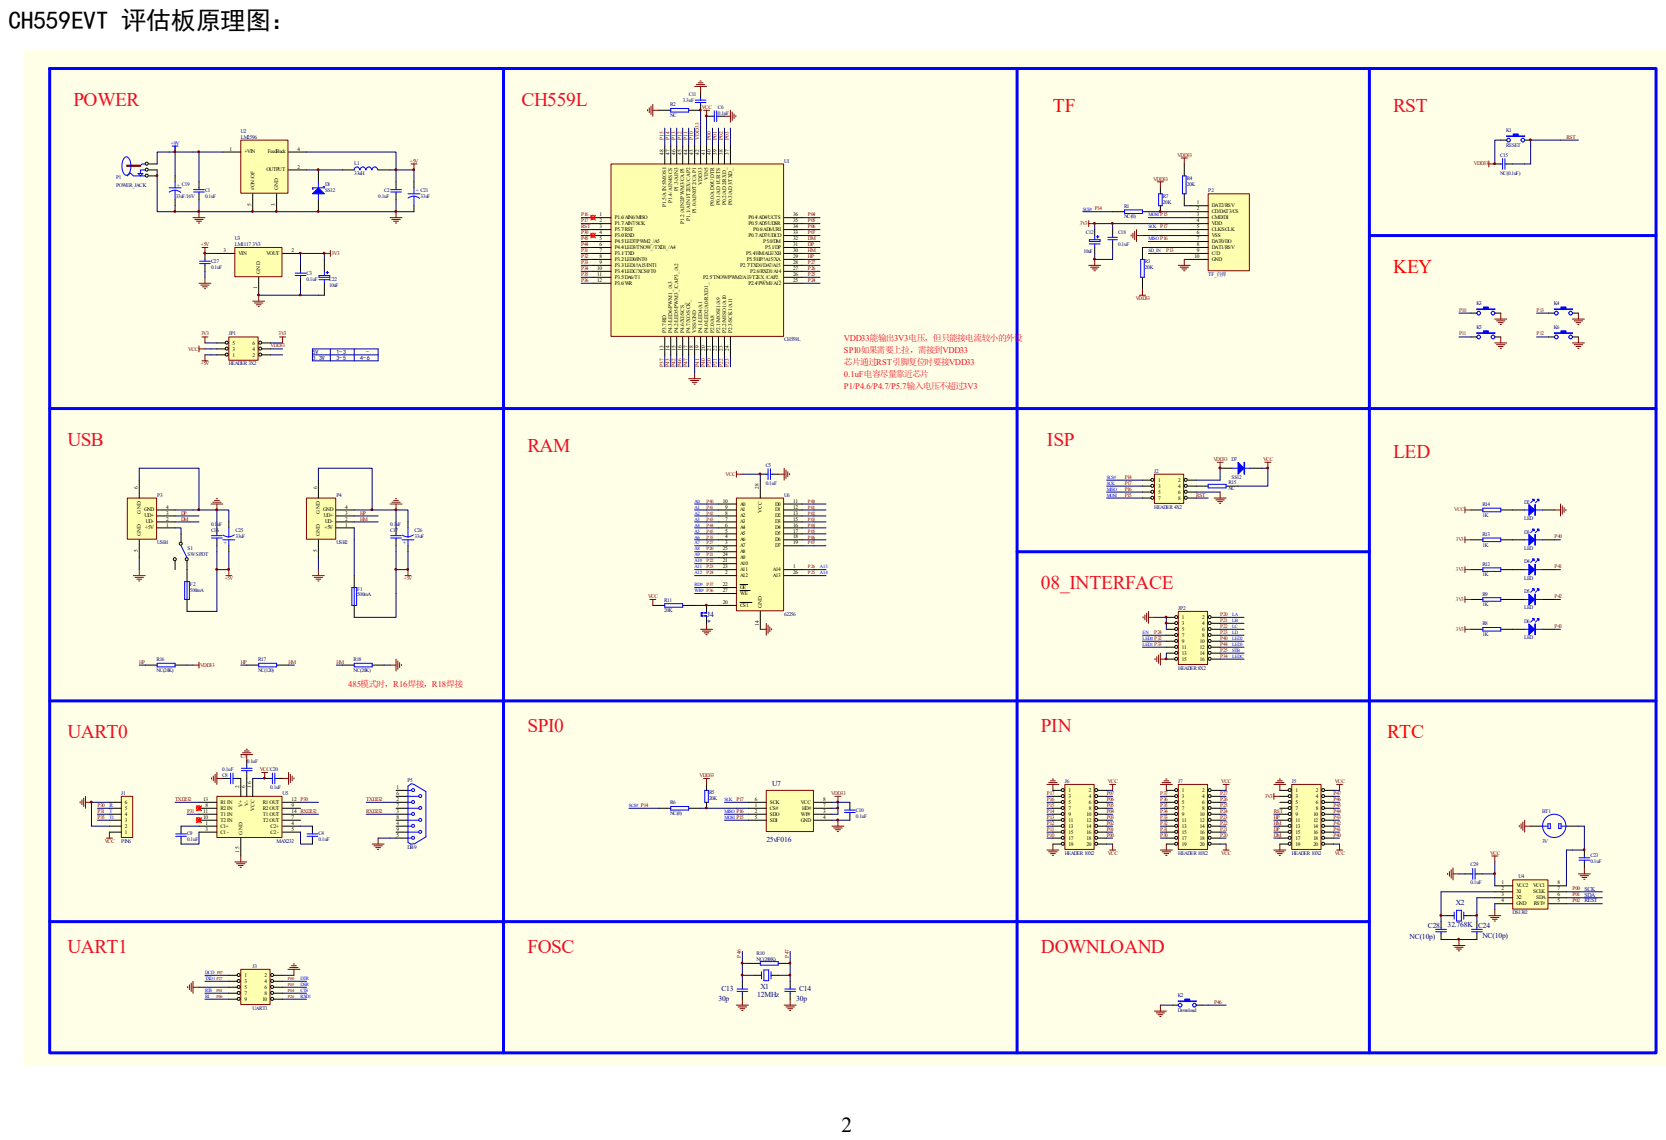
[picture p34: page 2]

5V | 1- 3 3- 5 | 4-6 VCC -

SCS# SCK MOSI MISO

2 V- 6 VCC 16 R1 OUT 12 R2 OUT 9 T1 OUT 14 T2 OUT 7 C1+ 1 C1 - 3 C2+ 4 C2 - 5 U5 MAX232 RXD232 TXD232 P30 P31 VCC

# POWER

# RST

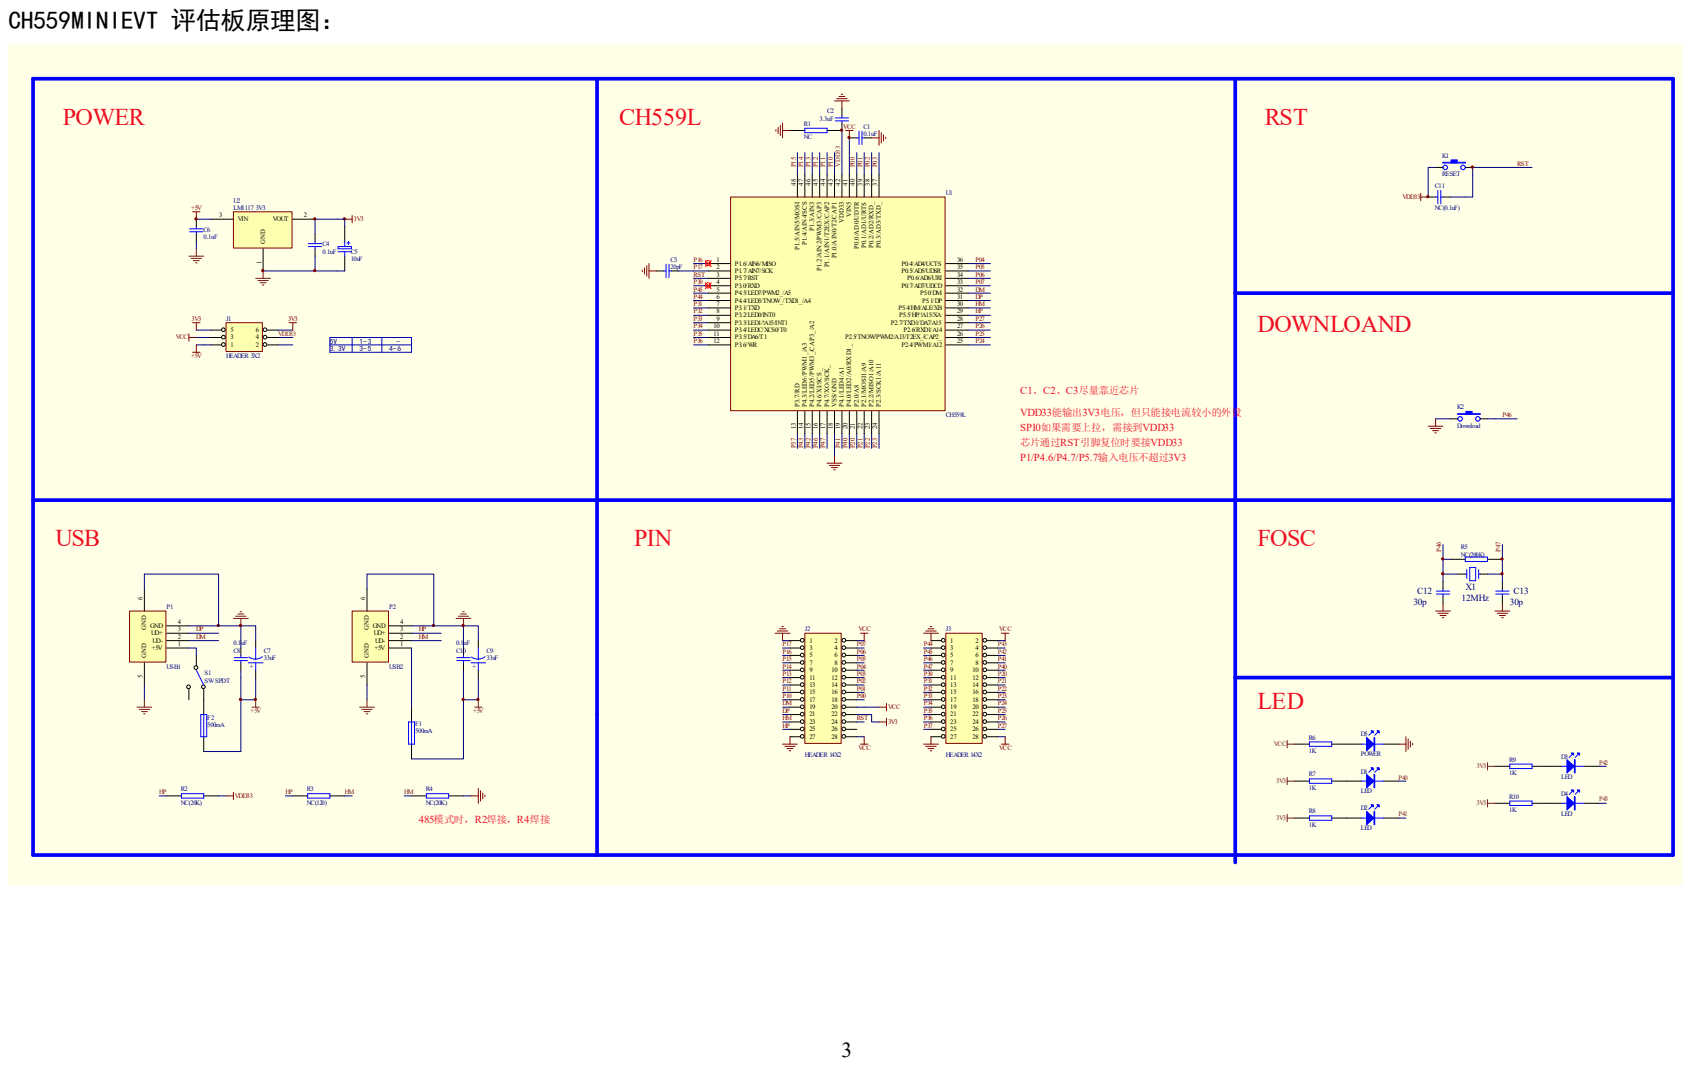
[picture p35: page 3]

5V | 1- 3 | -
3. 3V

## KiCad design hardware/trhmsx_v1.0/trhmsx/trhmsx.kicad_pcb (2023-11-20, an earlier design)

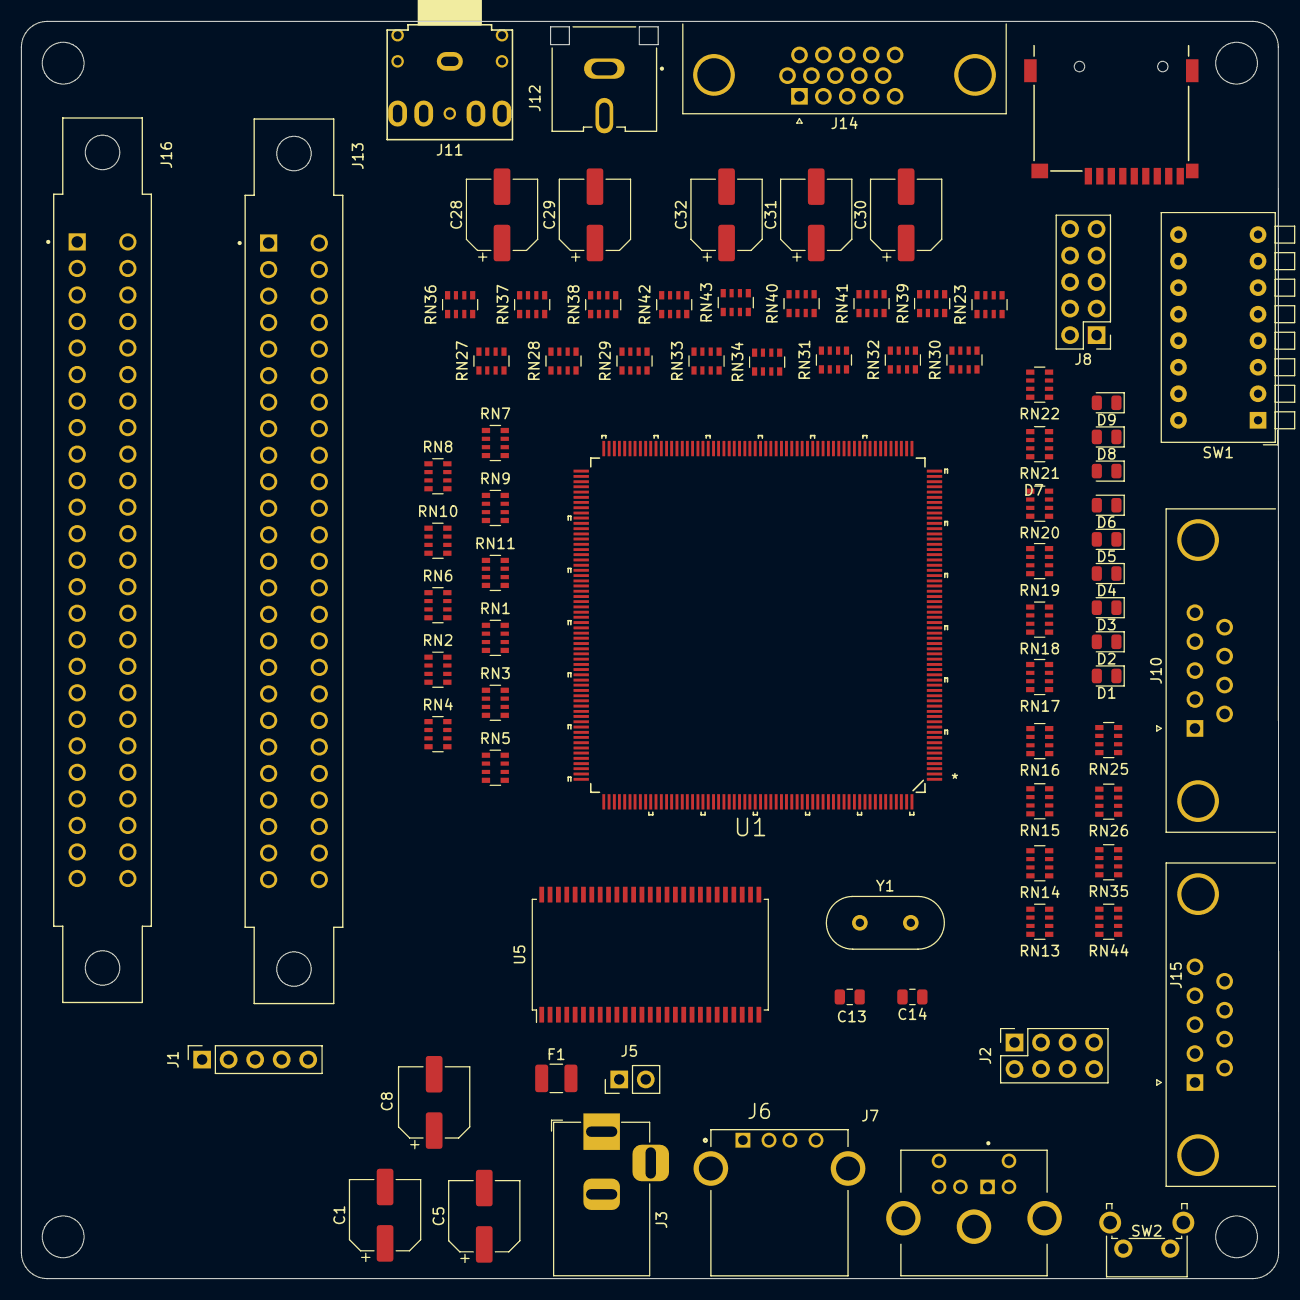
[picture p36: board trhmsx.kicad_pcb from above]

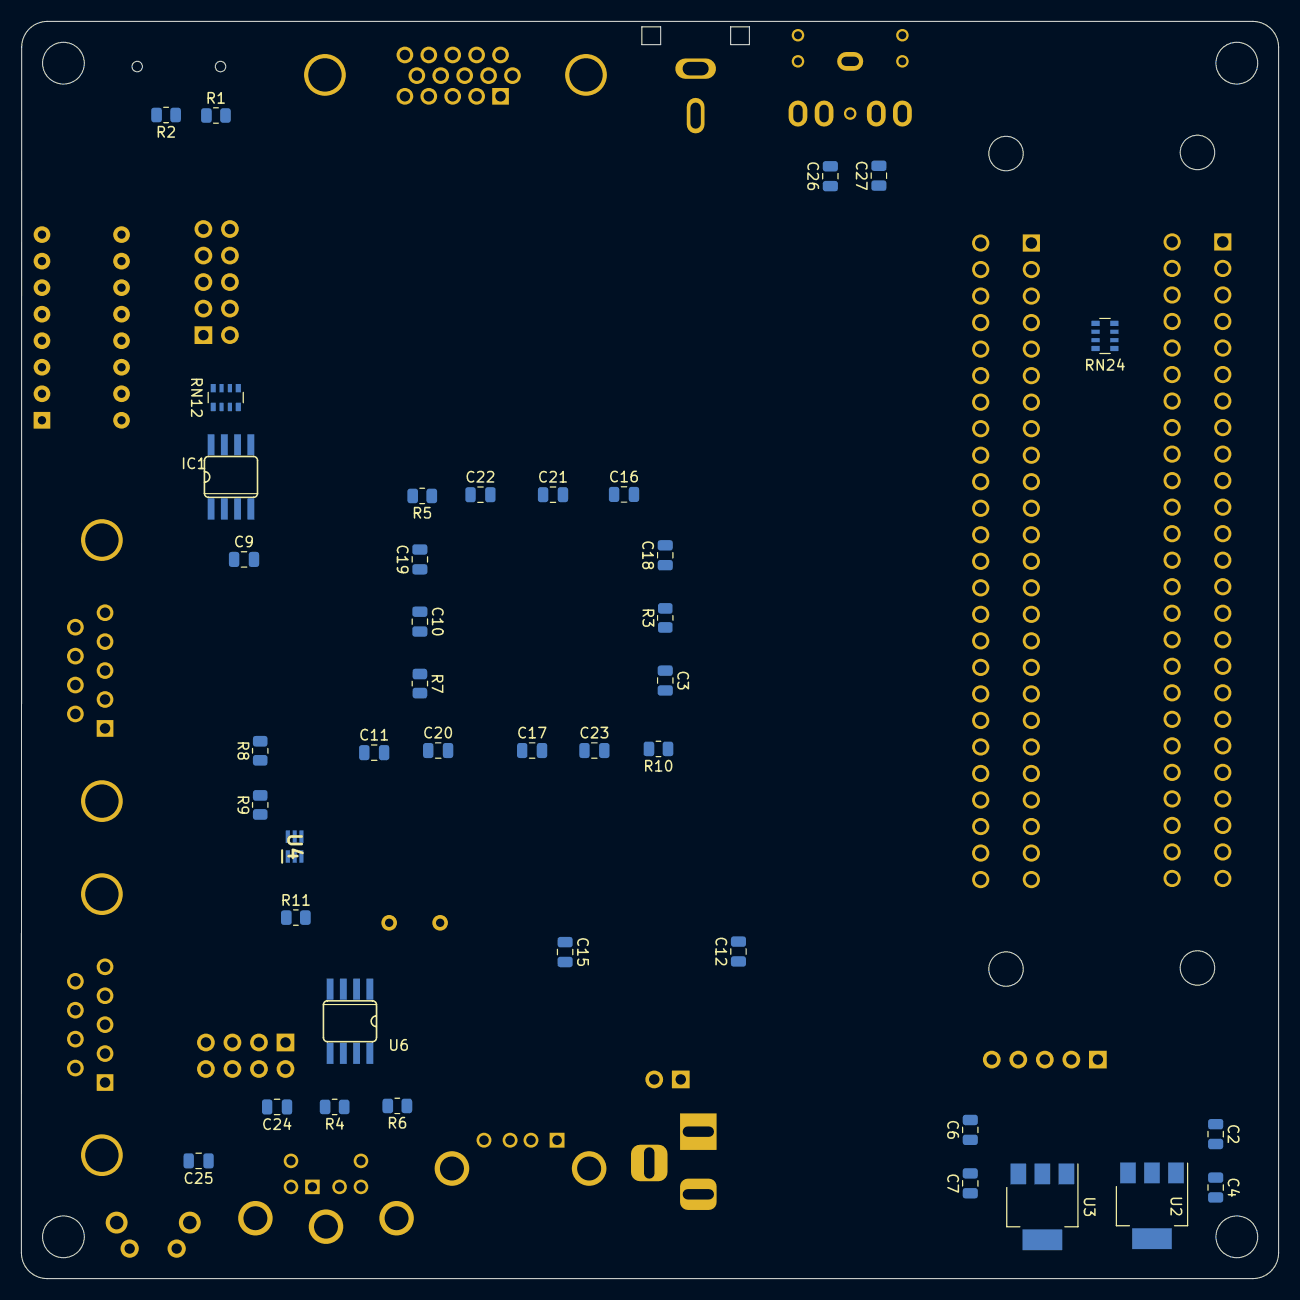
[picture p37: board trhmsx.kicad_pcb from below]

Board: 2 copper layers, 120.4 x 120.4 mm, 122 parts (40 on the bottom side), 307 nets, no tracks yet.

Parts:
C1, C5, C8, C28, C29, C30, C31, C32: 220uF; CP_Elec_6.3x3
C2, C3, C4, C6, C7, C9, C10, C11, C12, C15, C16, C17, C18, C19, C20, C21, C22, C23, C24: 0.1uF; C_0805_2012Metric
C13, C14: 27pF; C_0805_2012Metric
C25: 2.2uF; C_0805_2012Metric
C26, C27: 4.7uF; C_0805_2012Metric
D1, D2, D3, D4, D5, D6, D7, D8, D9: LED3; LED_0805_2012Metric
F1: Fuse; Fuse_1210_3225Metric
IC1: EPCS4; SO08
J1: MODULE-12V; PinSocket_1x05_P2.54mm_Vertical
J2: ESP-01; PinSocket_2x04_P2.54mm_Vertical
J3: Barrel_Jack; BarrelJack_Horizontal
J4: MICRO-SD; Conn_uSDcard
J5: Conn_01x02; PinHeader_1x02_P2.54mm_Vertical
J6: KEYBOARD-USB; TE_6364372-2
J7: KEYBOARD-PS2; TE_5749180-1
J8: Conn_02x05_Odd_Even; PinHeader_2x05_P2.54mm_Vertical
J10: JOY2; DSUB-9_Male_Horizontal_P2.77x2.84mm_EdgePinOffset4.94mm_Hou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
J11: AudioJack2_Ground; PJ-307
J12: RCA; CUI_RCJ-044
J13: CART2; TE_5530841-5
J14: DH15; DSUB-15-HD_Female_Horizontal_P2.29x1.98mm_EdgePinOffset3.03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
J15: JOY1; DSUB-9_Male_Horizontal_P2.77x2.84mm_EdgePinOffset4.94mm_Hou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
J16: CART1; TE_5530841-5
R1, R2: 10K; R_0805_2012Metric
R3, R7: 10; R_0805_2012Metric
R4, R5, R6: 1K; R_0805_2012Metric
R8, R9: 100; R_0805_2012Metric
R10: 22; R_0805_2012Metric
R11: 1M; R_0805_2012Metric
RN1, RN2, RN3, RN4, RN5, RN6, RN7, RN8, RN9, RN10, RN11, RN13, RN14, RN15, RN16, RN19, RN20, RN21, RN22, RN23, RN36, RN37, RN38, RN39, RN40, RN41, RN42, RN43: 100; R_Array_Convex_4x0603
RN12, RN25, RN26, RN35, RN44: 10K; R_Array_Convex_4x0603
RN17, RN18, RN24: 1K; R_Array_Convex_4x0603
RN27, RN28, RN29, RN30, RN31, RN32, RN33, RN34: 200; R_Array_Convex_4x0603
SW1: SW_DIP_x08; SW_DIP_SPSTx08_Piano_10.8x21.88mm_W7.62mm_P2.54mm
SW2: SW_Push; SW_Tactile_SPST_Angled_PTS645Vx83-2LFS
U1: EP1C12Q240C8N; QFP50P3460X3460X410-240N
U2: AMS1117-1.5; SOT-223-3_TabPin2
U3: AMS1117-3.3; SOT-223-3_TabPin2
U4: NC7WZU04P6X; SOT65P210X110-6N
U5: MT48LC16M16A2TG; TSOP-II-54_22.2x10.16mm_P0.8mm
U6: M51953BFP; SO08
Y1: 21.47727 MHz; Crystal_HC49-U_Vertical

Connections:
+1V5: C4.1, C5.1, C20.2, C21.2, C22.2, C23.2, R3.2, R7.2, U1.72 (VCCINT), U1.81 (VCCINT_5), U1.90 (VCCINT), U1.97 (VCCINT_2), U1.103 (VCCINT_4), U1.110 (VCCINT_3), U1.191 (VCCINT_2), U1.198 (VCCINT_3), U1.204 (VCCINT_4), U1.211 (VCCINT_5), U1.220 (VCCINT_6), U1.229 (VCCINT), U2.2 (VO)
+3.3V: C7.1, C8.1, C9.1, C11.1, C12.2, C15.1, C16.2, C17.2, C18.2, C19.2, IC1.3 (VCC@3), IC1.7 (VCC@7), IC1.8 (VCC@8), J2.4, J2.8, J4.4 (VDD), J8.4, R1.1, R2.1, R4.1, R6.1, RN12.1 (R1.1), RN12.2 (R2.1), RN12.3 (R3.1), RN24.1 (R1.1), RN24.2 (R2.1), RN24.3 (R3.1), RN24.4 (R4.1), RN25.6 (R3.2), RN25.7 (R2.2), RN25.8 (R1.2), RN26.5 (R4.2), RN26.6 (R3.2), RN26.7 (R2.2), RN26.8 (R1.2), RN35.6 (R3.2), RN35.7 (R2.2), RN35.8 (R1.2), RN44.5 (R4.2), RN44.6 (R3.2), RN44.7 (R2.2), RN44.8 (R1.2), U1.9 (VCCIO1), U1.22 (VCCIO1_2), U1.51 (VCCIO1_3), U1.70 (VCCIO4), U1.92 (VCCIO4_2), U1.112 (VCCIO4), U1.130 (VCCIO3_2), U1.148 (TMS), U1.155 (TDI), U1.157 (VCCIO3), U1.172 (VCCIO3), U1.189 (VCCIO2), U1.209 (VCCIO2_2), U1.231 (VCCIO2_3), U3.2 (VO), U4.5 (VCC), U5.1 (VDD), U5.3 (VDDQ), U5.9 (VDDQ), U5.14 (VDD), U5.27 (VDD), U5.43 (VDDQ), U5.49 (VDDQ)
+5V: C1.1, C2.1, C6.1, C24.1, J1.5, J5.2, J6.1 (VBUS), J7.4, J10.5, J13.45, J13.47, J14.9, J15.5, J16.45, J16.47, U2.3 (VI), U3.3 (VI), U6.7 (VCC)
+12V: J1.3, J13.48, J16.48
-12V: J1.1, J13.50, J16.50
/A0: J13.28, J16.28, RN2.2 (R2.1)
/A1: J13.27, J16.27, RN2.1 (R1.1)
/A2: J13.30, J16.30, RN2.4 (R4.1)
/A3: J13.29, J16.29, RN2.3 (R3.1)
/A4: J13.32, J16.32, RN3.2 (R2.1)
/A5: J13.31, J16.31, RN3.1 (R1.1)
/A6: J13.22, J16.22, RN6.4 (R4.1)
/A7: J13.21, J16.21, RN6.3 (R3.1)
/A8: J13.24, J16.24, RN1.2 (R2.1)
/A9: J13.17, J16.17, RN11.1 (R1.1)
/A10: J13.20, J16.20, RN11.4 (R4.1)
/A11: J13.19, J16.19, RN11.3 (R3.1)
/A12: J13.23, J16.23, RN1.1 (R1.1)
/A13: J13.26, J16.26, RN1.4 (R4.1)
/A14: J13.25, J16.25, RN1.3 (R3.1)
/A15: J13.18, J16.18, RN11.2 (R2.1)
/AS_CK: IC1.6 (DCLK), J8.1, U1.36 (DCLK)
/AS_CS: IC1.1 (NCS), J8.8, U1.24 (IO_22)
/AS_DI: IC1.2 (DATA), J8.7, U1.25 (DATA0)
/AS_DO: IC1.5 (ASDI), J8.9, U1.37 (IO_23)
/BDIR: J13.10, J16.10, RN9.3 (R3.1)
/CLK21M: R9.2, U1.28 (CLK0)
/CLOCK: J13.42, J16.42, RN6.2 (R2.1)
/CS1: J13.1, J16.1, RN7.2 (R2.1)
/CS2: J13.2, J16.2, RN7.3 (R3.1)
/CS12: J13.3, J16.3, RN7.4 (R4.1)
/C_CE: J8.6, RN12.5 (R4.2), U1.33 (NCE)
/C_CONF: J8.5, RN12.7 (R2.2), U1.26 (NCONFIG)
/C_DONE: J8.3, RN12.8 (R1.2), U1.145 (CONF_DONE)
/C_STAT: RN12.6 (R3.2), U1.146 (NSTATUS)
/D0: J13.34, J16.34, RN3.4 (R4.1)
/D1: J13.33, J16.33, RN3.3 (R3.1)
/D2: J13.36, J16.36, RN4.2 (R2.1)
/D3: J13.35, J16.35, RN4.1 (R1.1)
/D4: J13.38, J16.38, RN4.4 (R4.1)
/D5: J13.37, J16.37, RN4.3 (R3.1)
/D6: J13.40, J16.40, RN5.2 (R2.1)
/D7: J13.39, J16.39, RN5.1 (R1.1)
/DIP1: RN19.1 (R1.1), SW1.16
/DIP2: RN19.2 (R2.1), SW1.15
/DIP3: RN19.3 (R3.1), SW1.14
/DIP4: RN19.4 (R4.1), SW1.13
/DIP5: RN20.1 (R1.1), SW1.12
/DIP6: RN20.2 (R2.1), SW1.11
/DIP7: RN20.3 (R3.1), SW1.10
/DIP8: RN20.4 (R4.1), SW1.9
/EXTCLK: R8.2, U1.29 (CLK1)
/HSYNC: J14.13, RN23.3 (R3.1)
/INT: J13.8, J16.8, RN9.1 (R1.1)
/IO0: J15.1, RN13.1 (R1.1), RN44.1 (R1.1)
/IO1: J15.6, RN13.2 (R2.1), RN44.2 (R2.1)
/IO2: J15.2, RN13.3 (R3.1), RN44.3 (R3.1)
/IO3: J15.7, RN13.4 (R4.1), RN44.4 (R4.1)
/IO4: J15.3, RN14.1 (R1.1), RN35.1 (R1.1)
/IO5: J15.8, RN14.2 (R2.1), RN35.2 (R2.1)
/IO6: J15.4, RN14.3 (R3.1), RN35.3 (R3.1)
/IO7: J10.1, RN14.4 (R4.1), RN26.1 (R1.1)
/IO8: J10.6, RN15.1 (R1.1), RN26.2 (R2.1)
/IO9: J10.2, RN15.2 (R2.1), RN26.3 (R3.1)
/IO10: J10.7, RN15.3 (R3.1), RN26.4 (R4.1)
/IO11: J10.3, RN15.4 (R4.1), RN25.1 (R1.1)
/IO12: J10.8, RN16.1 (R1.1), RN25.2 (R2.1)
/IO13: J10.4, RN16.2 (R2.1), RN25.3 (R3.1)
/IORQ: J13.11, J16.11, RN9.4 (R4.1)
/KCLK: J6.3 (D+), J7.5, R4.2, RN22.4 (R4.1)
/KDAT: J6.2 (D-), J7.1, R6.2, RN22.3 (R3.1)
/LED1: D1.2 (A), RN17.1 (R1.1)
/LED2: D2.2 (A), RN17.2 (R2.1)
/LED3: D3.2 (A), RN17.3 (R3.1)
/LED4: D4.2 (A), RN17.4 (R4.1)
/LED5: D5.2 (A), RN18.1 (R1.1)
/LED6: D6.2 (A), RN18.2 (R2.1)
/LED7: D7.2 (A), RN18.3 (R3.1)
/LED8: D8.2 (A), RN18.4 (R4.1)
/M1: J13.9, J16.9, RN9.2 (R2.1)
/MA0: U1.203 (IO_36), U5.23 (A0)
/MA1: U1.206 (IO_37), U5.24 (A1)
/MA2: U1.207 (IO_38), U5.25 (A2)
/MA3: U1.208 (IO_39), U5.26 (A3)
/MA4: U1.235 (IO_56), U5.29 (A4)
/MA5: U1.234 (IO_55), U5.30 (A5)
/MA6: U1.233 (IO_54), U5.31 (A6)
/MA7: U1.228 (IO_53), U5.32 (A7)
/MA8: U1.227 (IO_52), U5.33 (A8)
/MA9: U1.226 (IO_51), U5.34 (A9)
/MA10: U1.202 (IO_35), U5.22 (A10)
/MA11: U1.225 (IO_50), U5.35 (A11)
/MA12: U1.224 (IO_49), U5.36 (A12)
/MBA0: U1.200 (IO_33), U5.20 (BA0)
/MBA1: U1.201 (IO_34), U5.21 (BA1)
/MCAS: U1.195 (IO_30), U5.17 (~CAS)
/MCKE: U1.39 (IO_25), U5.37 (CKE)
/MCLK: R10.1, U5.38 (CLK)
/MCS: U1.197 (IO_32), U5.19 (~CS)
/MD0: U1.181 (IO_20), U5.2 (DQ0)
/MD1: U1.182 (IO_21), U5.4 (DQ1)
/MD2: U1.183 (IO_22), U5.5 (DQ2)
/MD3: U1.184 (IO_23), U5.7 (DQ3)
/MD4: U1.185 (IO_24), U5.8 (DQ4)
/MD5: U1.186 (IO_25), U5.10 (DQ5)
/MD6: U1.187 (IO_26), U5.11 (DQ6)
/MD7: U1.188 (IO_27), U5.13 (DQ7)
/MD8: U1.222 (IO_47), U5.42 (DQ8)
/MD9: U1.219 (IO_46), U5.44 (DQ9)
/MD10: U1.218 (IO_45), U5.45 (DQ10)
/MD11: U1.217 (IO_44), U5.47 (DQ11)
/MD12: U1.216 (IO_43), U5.48 (DQ12)
/MD13: U1.215 (IO_42), U5.50 (DQ13)
/MD14: U1.214 (IO_41), U5.51 (DQ14)
/MD15: U1.213 (IO_40), U5.53 (DQ15)
/MERQ: J13.12, J16.12, RN10.1 (R1.1)
/MLDQ: U1.193 (IO_28), U5.15 (DQML)
/MRAS: U1.196 (IO_31), U5.18 (~RAS)
/MUDQ: U1.223 (IO_48), U5.39 (DQMH)
/MWE: U1.194 (IO_29), U5.16 (~WE)
/PWRLED: R5.1, U1.240 (IO)
/RD: J13.14, J16.14, RN10.3 (R3.1)
/RESET: J13.15, J16.15, RN6.1 (R1.1), RN24.8 (R1.2), U6.6 (OUT)
/RFSH: J13.6, J16.6, RN8.3 (R3.1), RN24.5 (R4.2)
/RSV5: J13.5, J16.5, RN8.2 (R2.1), RN24.7 (R2.2)
/RSV16: J13.16, J16.16, RN10.4 (R4.1), RN24.6 (R3.2)
/SCLK: J14.12, RN23.4 (R4.1)
/SDAT: J14.15, RN23.1 (R1.1)
/SD_CK: J4.5 (CLK), R2.2, RN21.3 (R3.1)
/SD_CM: J4.3 (CMD), R1.2, RN21.4 (R4.1)
/SD_D0: J4.7 (DAT0), RN21.2 (R2.1)
/SD_D1: J4.8 (DAT1), RN21.1 (R1.1)
/SD_D2: J4.1 (DAT2), RN22.2 (R2.1)
/SD_D3: J4.2 (DAT3/CD), RN22.1 (R1.1)
/SL0: RN29.4 (R4.1), U1.105 (IO_17)
/SL1: RN29.3 (R3.1), U1.106 (IO_18)
/SL2: RN29.2 (R2.1), U1.107 (IO_19)
/SL3: RN29.1 (R1.1), U1.108 (IO_20)
/SL4: RN28.4 (R4.1), U1.113 (IO_21)
/SL5: RN28.3 (R3.1), U1.114 (IO_22)
/SLTSL1: J16.4, RN8.1 (R1.1)
/SLTSL2: J13.4, RN7.1 (R1.1)
/SOUND_L: C26.2, C27.2, C29.2, J11.T
/SOUND_R: C28.2, J11.S
/SR0: RN28.2 (R2.1), U1.115 (IO_23)
/SR1: RN28.1 (R1.1), U1.116 (IO_24)
/SR2: RN27.4 (R4.1), U1.117 (IO_25)
/SR3: RN27.3 (R3.1), U1.118 (IO_26)
/SR4: RN27.2 (R2.1), U1.119 (IO_27)
/SR5: RN27.1 (R1.1), U1.120 (IO_28)
/SW1: J13.44, J16.44, RN5.3 (R3.1)
/SW2: J13.46, J16.46, RN5.4 (R4.1)
/USBN1: J2.2, U1.236 (IO_57)
/USBP1: J2.7, U1.237 (IO_58)
/VB0: RN31.2 (R2.1), U1.77 (IO_56)
/VB1: RN31.1 (R1.1), U1.78 (IO_57)
/VB2: RN30.4 (R4.1), U1.79 (IO)
/VB3: RN30.3 (R3.1), U1.82 (IO_2)
/VB4: RN30.2 (R2.1), U1.83 (IO_3)
/VB5: RN30.1 (R1.1), U1.84 (IO_4)
/VB_CV: C30.2, J12.1 (In), J14.3
/VG0: RN32.4 (R4.1), U1.85 (IO_5)
/VG1: RN32.3 (R3.1), U1.86 (IO_6)
/VG2: RN32.2 (R2.1), U1.87 (IO_7)
/VG3: RN32.1 (R1.1), U1.88 (IO_8)
/VG4: RN31.4 (R4.1), U1.93 (IO_9)
/VG5: RN31.3 (R3.1), U1.94 (IO_10)
/VG_SY: C31.2, J14.2
/VR0: RN34.2 (R2.1), U1.95 (IO_11)
/VR1: RN34.1 (R1.1), U1.98 (IO_12)
/VR2: RN33.4 (R4.1), U1.99 (IO_13)
/VR3: RN33.3 (R3.1), U1.100 (IO_14)
/VR4: RN33.2 (R2.1), U1.101 (IO_15)
/VR5: RN33.1 (R1.1), U1.104 (IO_16)
/VR_SC: C32.2, J14.1
/VSYNC: J14.14, RN23.2 (R2.1)
/WAIT: J13.7, J16.7, RN8.4 (R4.1)
/WR: J13.13, J16.13, RN10.2 (R2.1)
GND: C1.2, C2.2, C3.2, C4.2, C5.2, C6.2, C7.2, C8.2, C9.2, C10.2, C12.1, C13.2, C14.2, C15.2, C16.1, C17.1, C18.1, C19.1, C20.1, C21.1, C22.1, C23.1, C24.2, C25.2, D1.1 (K), D2.1 (K), D3.1 (K), D4.1 (K), D5.1 (K), D6.1 (K), D7.1 (K), D8.1 (K), D9.1 (K), IC1.4 (GND), J1.2, J1.4, J2.1, J3.2, J4.6 (VSS), J6.4 (GND), J6.5 (Shield), J7.3, J8.2, J8.10, J10.9, J11.G, J12.2 (Ext), J13.41, J13.43, J14.5, J14.6, J14.7, J14.8, J14.10, J15.9, J16.41, J16.43, RN12.4 (R4.1), RN37.7 (R2.2), RN38.5 (R4.2), RN40.7 (R2.2), RN41.5 (R4.2), RN43.7 (R2.2), SW1.1, SW1.2, SW1.3, SW1.4, SW1.5, SW1.6, SW1.7, SW1.8, SW2.1, U1.10 (GND_3), U1.30 (GNDA_PLL1), U1.31 (GNDG_PLL1), U1.34 (MSEL0), U1.35 (MSEL1), U1.40 (GND_4), U1.52 (GND_5), U1.69 (GND_6), U1.71 (GND), U1.80 (GND_2), U1.89 (GND_2), U1.91 (GND_4), U1.96 (GND_5), U1.102 (GND_6), U1.109 (GND_7), U1.111 (GND_8), U1.129 (GND), U1.142 (GND_3), U1.147 (TCK), U1.150 (GNDG_PLL2), U1.151 (GNDA_PLL2), U1.171 (GND_2), U1.190 (GND_4), U1.192 (GND_3), U1.199 (GND_5), U1.205 (GND_6), U1.210 (GND_8), U1.212 (GND), U1.221 (GND_9), U1.230 (GND_7), U1.232 (GND_10), U2.1 (GND), U3.1 (GND), U4.2 (GND), U5.6 (VSSQ), U5.12 (VSSQ), U5.28 (VSS), U5.41 (VSS), U5.46 (VSSQ), U5.52 (VSSQ), U5.54 (VSS), U6.4 (GND)
unnamed: D9.2 (A), R5.2
unnamed: F1.1, J3.1
unnamed: F1.2, J5.1
unnamed: C26.1, J13.49
unnamed: C27.1, J16.49
unnamed: RN1.8 (R1.2), U1.159 (IO_52)
unnamed: RN1.7 (R2.2), U1.160 (IO)
unnamed: RN1.6 (R3.2), U1.161 (IO_2)
unnamed: RN1.5 (R4.2), U1.162 (IO_3)
unnamed: RN2.8 (R1.2), U1.163 (IO_4)
unnamed: RN2.7 (R2.2), U1.164 (IO_5)
unnamed: RN2.6 (R3.2), U1.165 (IO_6)
unnamed: RN2.5 (R4.2), U1.166 (IO_7)
unnamed: RN3.8 (R1.2), U1.167 (IO_8)
unnamed: RN3.7 (R2.2), U1.168 (IO_9)
unnamed: RN3.6 (R3.2), U1.169 (IO_10)
unnamed: RN3.5 (R4.2), U1.170 (IO_11)
unnamed: RN4.8 (R1.2), U1.173 (IO_12)
unnamed: RN4.7 (R2.2), U1.174 (IO_13)
unnamed: RN4.6 (R3.2), U1.175 (IO_14)
unnamed: RN4.5 (R4.2), U1.176 (IO_15)
unnamed: RN5.8 (R1.2), U1.177 (IO_16)
unnamed: RN5.7 (R2.2), U1.178 (IO_17)
unnamed: RN5.6 (R3.2), U1.179 (IO_18)
unnamed: RN5.5 (R4.2), U1.180 (IO_19)
unnamed: RN6.8 (R1.2), U1.153 (CLK2)
unnamed: RN6.7 (R2.2), U1.144 (IO_49), U1.152 (CLK3)
unnamed: RN6.6 (R3.2), U1.156 (IO_50)
unnamed: RN6.5 (R4.2), U1.158 (IO_51)
unnamed: RN7.8 (R1.2), U1.121 (IO_29)
unnamed: RN7.7 (R2.2), U1.122 (IO_30)
unnamed: RN7.6 (R3.2), U1.123 (IO_31)
unnamed: RN7.5 (R4.2), U1.124 (IO_32)
unnamed: RN8.8 (R1.2), U1.125 (IO_33)
unnamed: RN8.7 (R2.2), U1.126 (IO_34)
unnamed: RN8.6 (R3.2), U1.127 (IO_35)
unnamed: RN8.5 (R4.2), U1.128 (IO_36)
unnamed: RN9.8 (R1.2), U1.131 (IO_37)
unnamed: RN9.7 (R2.2), U1.132 (IO_38)
unnamed: RN9.6 (R3.2), U1.133 (IO_39)
unnamed: RN9.5 (R4.2), U1.134 (IO_40)
unnamed: RN10.8 (R1.2), U1.135 (IO_41)
unnamed: RN10.7 (R2.2), U1.136 (IO_42)
unnamed: RN10.6 (R3.2), U1.137 (IO_43)
unnamed: RN10.5 (R4.2), U1.138 (IO_44)
unnamed: RN11.8 (R1.2), U1.139 (IO_45)
unnamed: RN11.7 (R2.2), U1.140 (IO_46)
unnamed: RN11.6 (R3.2), U1.141 (IO_47)
unnamed: RN11.5 (R4.2), U1.143 (IO_48)
unnamed: RN13.8 (R1.2), U1.1 (IO_2)
unnamed: RN13.7 (R2.2), U1.2 (IO_3)
unnamed: RN13.6 (R3.2), U1.3 (IO_4)
unnamed: RN13.5 (R4.2), U1.4 (IO_5)
unnamed: RN14.8 (R1.2), U1.5 (IO_6)
unnamed: RN14.7 (R2.2), U1.6 (IO_7)
unnamed: RN14.6 (R3.2), U1.7 (IO_8)
unnamed: RN14.5 (R4.2), U1.8 (IO_9)
unnamed: RN15.8 (R1.2), U1.11 (IO_10)
unnamed: RN15.7 (R2.2), U1.12 (IO_11)
unnamed: RN15.6 (R3.2), U1.13 (IO_12)
unnamed: RN15.5 (R4.2), U1.14 (IO_13)
unnamed: RN16.8 (R1.2), U1.15 (IO_14)
unnamed: RN16.7 (R2.2), U1.16 (IO_15)
unnamed: RN17.8 (R1.2), U1.43 (IO_28)
unnamed: RN17.7 (R2.2), U1.44 (IO_29)
unnamed: RN17.6 (R3.2), U1.45 (IO_30)
unnamed: RN17.5 (R4.2), U1.46 (IO_31)
unnamed: RN18.8 (R1.2), U1.47 (IO_32)
unnamed: RN18.7 (R2.2), U1.48 (IO_33)
unnamed: RN18.6 (R3.2), U1.49 (IO_34)
unnamed: RN18.5 (R4.2), U1.50 (IO_35)
unnamed: RN19.8 (R1.2), U1.53 (IO_36)
unnamed: RN19.7 (R2.2), U1.54 (IO_37)
unnamed: RN19.6 (R3.2), U1.55 (IO_38)
unnamed: RN19.5 (R4.2), U1.56 (IO_39)
unnamed: RN20.8 (R1.2), U1.57 (IO_40)
unnamed: RN20.7 (R2.2), U1.58 (IO_41)
unnamed: RN20.6 (R3.2), U1.59 (IO_42)
unnamed: RN20.5 (R4.2), U1.60 (IO_43)
unnamed: RN21.8 (R1.2), U1.61 (IO_44)
unnamed: RN21.7 (R2.2), U1.62 (IO_45)
unnamed: RN21.6 (R3.2), U1.63 (IO_46)
unnamed: RN21.5 (R4.2), U1.64 (IO_47)
unnamed: RN22.8 (R1.2), U1.65 (IO_48)
unnamed: RN22.7 (R2.2), U1.66 (IO_49)
unnamed: RN22.6 (R3.2), U1.67 (IO_50)
unnamed: RN22.5 (R4.2), U1.68 (IO_51)
unnamed: RN23.8 (R1.2), U1.73 (IO_52)
unnamed: RN23.7 (R2.2), U1.74 (IO_53)
unnamed: RN23.6 (R3.2), U1.75 (IO_54)
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

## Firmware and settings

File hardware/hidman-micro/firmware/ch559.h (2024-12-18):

#ifndef __CH559_H__
#define __CH559_H__

typedef unsigned char volatile __xdata    UINT8XV;
typedef unsigned char volatile __pdata    UINT8PV;

#include <compiler.h>
#include <stdint.h>
#include <stdbool.h>

//#define DEBUG

/*----- SFR --------------------------------------------------------------*/
/*  sbit are bit addressable, others are byte addressable */

/*  System Registers  */
SFR(PSW,	0xD0);	// program status word
   SBIT(CY,	0xD0, 7);	// carry flag
   SBIT(AC,	0xD0, 6);	// auxiliary carry flag
   SBIT(F0,	0xD0, 5);	// bit addressable general purpose flag 0
   SBIT(RS1,	0xD0, 4);	// register R0-R7 bank selection high bit
   SBIT(RS0,	0xD0, 3);	// register R0-R7 bank selection low bit
#define MASK_PSW_RS       0x18      // bit mask of register R0-R7 bank selection
// RS1 & RS0: register R0-R7 bank selection
//    00 - bank 0, R0-R7 @ address 0x00-0x07
//    01 - bank 1, R0-R7 @ address 0x08-0x0F
//    10 - bank 2, R0-R7 @ address 0x10-0x17
//    11 - bank 3, R0-R7 @ address 0x18-0x1F
   SBIT(OV,	0xD0, 2);	// overflow flag
   SBIT(F1,	0xD0, 1);	// bit addressable general purpose flag 1
   SBIT(P,	0xD0, 0);	// ReadOnly: parity flag
SFR(ACC,	0xE0);	// accumulator
SFR(B,	0xF0);	// general purpose register B
SFR(SP,	0x81);	// stack pointer
//sfr16 DPTR          = 0x82;         // DPTR pointer, little-endian
SFR(DPL,	0x82);	// data pointer low
SFR(DPH,	0x83);	// data pointer high
SFR(SAFE_MOD,	0xA1);	// WriteOnly: writing safe mode
//sfr CHIP_ID         = 0xA1;         // ReadOnly: reading chip ID
#define CHIP_ID           SAFE_MOD
SFR(GLOBAL_CFG,	0xB1);	// global config, Write@SafeMode
#define bBOOT_LOAD        0x20      // ReadOnly: boot loader status for discriminating BootLoader or Application: set 1 by power on reset, clear 0 by software reset
#define bSW_RESET         0x10      // software reset bit, auto clear by hardware
#define bCODE_WE          0x08      // enable flash-ROM (include code & data area) being program or erasing: 0=writing protect, 1=enable program and erase
#define bDATA_WE          0x04      // enable Data-Flash (flash-ROM data area) being program or erasing: 0=writing protect, 1=enable program and erase
#define bXIR_XSFR         0x02      // force MOVX_@R0/@R1 only for xSFR area: 0=MOVX_@R0/@R1 for standard xdata area inclde xRAM&xBUS&xSFR, 1=MOVX_@R0/@R1 for xSFR only
#define bWDOG_EN          0x01      // enable watch-dog reset if watch-dog timer overflow: 0=as timer only, 1=enable reset if timer overflow

/* Clock and Sleep and Power Registers */
SFR(PCON,	0x87);	// power control and reset flag
#define SMOD              0x80      // baud rate selection for UART0 mode 1/2/3: 0=slow(Fsys/128 @mode2, TF1/32 @mode1/3, no effect for TF2),
                                    //   1=fast(Fsys/32 @mode2, TF1/16 @mode1/3, no effect for TF2)
#define bRST_FLAG1        0x20      // ReadOnly: recent reset flag high bit
#define bRST_FLAG0        0x10      // ReadOnly: recent reset flag low bit
#define MASK_RST_FLAG     0x30      // ReadOnly: bit mask of recent reset flag
#define RST_FLAG_SW       0x00
#define RST_FLAG_POR      0x10
#define RST_FLAG_WDOG     0x20
#define RST_FLAG_PIN      0x30
// bPC_RST_FLAG1 & bPC_RST_FLAG0: recent reset flag
//    00 - software reset, by bSW_RESET=1 @(bBOOT_LOAD=0 or bWDOG_EN=1)
//    01 - power on reset
//    10 - watch-dog timer overflow reset
//    11 - external input manual reset by RST pin
#define GF1               0x08      // general purpose flag bit 1
#define GF0               0x04      // general purpose flag bit 0
#define PD                0x02      // power-down enable bit, auto clear by wake-up hardware
SFR(PLL_CFG,	0xB2);	// PLL clock config: lower 5 bits for PLL clock Fpll, upper 3 bits for USB 4x clock Fusb4x, Write@SafeMode
#define MASK_PLL_MULT     0x1F      // bit mask of PLL clock Fpll multiple
#define MASK_USB_4X_DIV   0xE0      // bit mask of USB 4x clock Fusb4x divisor, value 000b means 1000b
SFR(CLOCK_CFG,	0xB3);	// system clock config: lower 5 bits for system clock Fsys, Write@SafeMode
#define bOSC_EN_INT       0x80      // internal oscillator enable and original clock selection: 1=enable & select internal clock, 0=disable & select external clock
#define bOSC_EN_XT        0x40      // external oscillator enable, need quartz crystal or ceramic resonator between X1 and X2 pins
#define bWDOG_IF_TO       0x20      // ReadOnly: watch-dog timer overflow interrupt flag, cleared by reload watch-dog count or auto cleared when MCU enter interrupt routine
#define MASK_SYS_CK_DIV   0x1F      // bit mask of system clock Fsys divisor, value 00000b means 100000b
/*
   Fxt = 4MHz~20MHz, from external oscillator @XI&XO
   Fosc = bOSC_EN_INT ? 12MHz : Fxt
   Fpll = Fosc * ( PLL_CFG & MASK_PLL_MULT ) => 288MHz (24MHz~350MHz)
   Kusb = ( PLL_CFG & MASK_USB_4X_DIV ) >> 5
   Fusb4x = Fpll / ( Kusb ? Kusb : 8 ) => 48MHz (Fixed)
   Ksys = CLOCK_CFG & MASK_SYS_CK_DIV
   Fsys = Fpll / ( Ksys ? Ksys : 32 ) => 12MHz (1MHz~56MHz)
*/
SFR(SLEEP_CTRL,	0xEA);	// sleep control, Write@SafeMode
#define bSLP_OFF_USB      0x80      // clock off for USB
#define bSLP_OFF_ADC      0x40      // clock off for ADC
#define bSLP_OFF_UART1    0x20      // clock off for UART1
#define bSLP_OFF_P1S1     0x10      // clock off for PWM1 / SPI1
#define bSLP_OFF_SPI0     0x08      // clock off for SPI0
#define bSLP_OFF_TMR3     0x04      // clock off for timer3
#define bSLP_OFF_LED      0x02      // clock off for LED
#define bSLP_OFF_XRAM     0x01      // clock off for xRAM
SFR(WAKE_CTRL,	0xEB);	// wake-up control, Write@SafeMode
#define bWAK_BY_USB       0x80      // enable wake-up by USB event
#define bWAK_RXD1_LO      0x40      // enable wake-up by RXD1 low level
#define bWAK_P1_5_LO      0x20      // enable wake-up by pin P1.5 low level
#define bWAK_P1_4_LO      0x10      // enable wake-up by pin P1.4 low level
#define bWAK_P0_3_LO      0x08      // enable wake-up by pin P0.3 low level
#define bWAK_CAP3_LO      0x04      // enable wake-up by CAP3 low level
#define bWAK_P3_2E_3L     0x02      // enable wake-up by pin P3.2 (INT0) edge or pin P3.3 (INT1) low level
#define bWAK_RXD0_LO      0x01      // enable wake-up by RXD0 low level
SFR(RESET_KEEP,	0xFE);	// value keeper during reset
SFR(WDOG_COUNT,	0xFF);	// watch-dog count, count by clock frequency Fsys/262144
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

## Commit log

2023-09-25 Sunday work
    [trhmsx.kicad_pcb, trhmsx.kicad_sch]
2023-09-27 working on the base circuit
    [trhmsx.kicad_sch]
2023-09-27 PS/2 and USB for simple keyboards
    [trhmsx.kicad_sch]
2023-10-02 Joysticks, memory and active serial config
    [trhmsx.kicad_sch]
2023-10-09 finishing FPGA wiring
    [trhmsx.kicad_sch]
2023-10-09 USB wiring
    [trhmsx.kicad_sch]
2023-10-09 wifi usb dongle
    [wificard.kicad_sch]
2023-10-30 First version of the PCB
    [trhmsx.kicad_pcb, trhmsx.kicad_sch]
2023-11-20 Initial placement
    [trhmsx.kicad_pcb, trhmsx.kicad_sch]
2023-11-26 routing phase 1
    [trhmsx.kicad_sch]
2023-11-26 pcb image
2023-12-29 Gerbers and small adjustments
    [bom.csv, designators.csv, positions.csv]
2024-03-10 1.2 update
    [TRHMSX_cart_guide_v1.1.stl, TRHMSX_cart_guide_v1.2.stl, TRHMSX_cart_guide_v1.3.stl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]
2024-03-10 license fix
    [trhmsx.kicad_sch]
2024-03-24 pin header for enabling the ESP-01
    [trhmsx.kicad_sch]
2024-04-25 minor changes
    [bom.csv, positions.csv, trhmsx.kicad_sch]
2024-04-25 interactive BOM
2024-04-25 removing case old versions
    [TRHMSX_cart_guide_v1.1.stl, TRHMSX_cart_guide_v1.2.stl, TRHMSX_cart_guide_v1.3.stl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]
2024-05-06 Covers for the case holes and top cover in STL
    [TRHMSX_Cartridge_Slot_Cover.stl, TRHMSX_Side_Cover_1.stl, TRHMSX_Side_Cover_2.stl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]
2024-05-06 Transucent Cover
    [TRHMSX_Translucent_Cover.stl, TRHMSX_Transucent_Cover.stl]
2024-06-04 1.4 release. minor fixes.
    [bom.csv, positions.csv, trhmsx.kicad_sch]
2024-11-01 fixed the 3d printed translucent cover
    [TRHMSX Translucent Cover.stl, TRHMSX_Translucent_Cover.stl]
2024-11-10 v1.5 wip - general USB keyboards and s-video
    [TRHMSX_case_base_v1.6.stl, bom.csv, designators.csv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]
2024-11-15 Case update
    [TRHMSX_case_base_v1.5.stl, TRHMSX_case_base_v1.6.stl, TRHMSX_case_base_v1.8.stl]
2024-12-31 Recompiling the firmware to support USB keyboards, fix for SVIDEO. 1.51 release.
    [trhmsx.kicad_sch]
2024-12-31 1.51 gerbers and BOM
    [positions.csv]
2025-01-01 v1.51 and content organization
    [bom.csv, designators.csv, positions.csv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]
